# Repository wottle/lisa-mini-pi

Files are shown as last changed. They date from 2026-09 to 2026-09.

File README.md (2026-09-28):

# Lisa Mini Pi

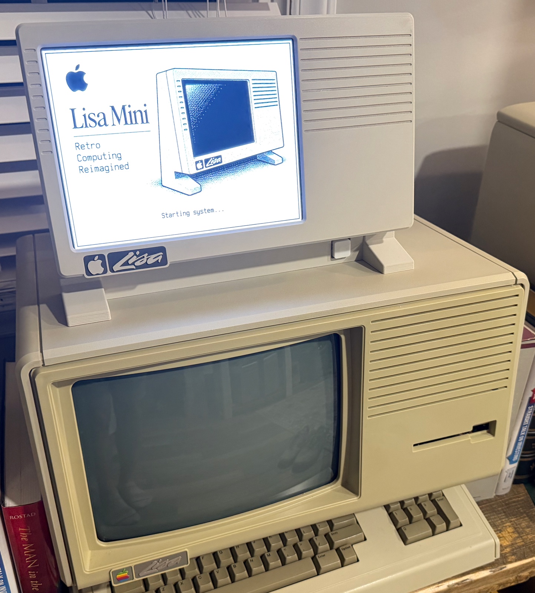
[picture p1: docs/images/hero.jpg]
Lisa Mini Pi booting, sitting atop a real Apple Lisa


A Raspberry Pi in a 3D-printed Apple Lisa-shaped case with a 1024x768 HDMI
LCD panel, booting straight into a "CHOOSE YOUR ADVENTURE" kiosk launcher
that lets you pick which vintage system to run:

- **Apple Lisa** — Office System 3.1, via a patched `LisaEm`
- **Classic Mac OS 6** — via Mini vMac
- **Classic Mac OS 7** — via Basilisk II
- **NeXTSTEP 3.3** — via Previous
- **Apple II** — via LinApple, boots straight into Total Replay (a
  ready-to-play library of Apple II games)

A physical GPIO power button + LED are wired up for the systems that
support a clean button-triggered shutdown (Lisa, NeXT, Apple II) — see
`docs/software-setup.md` §2.

## Screenshots

All on real hardware, 2026-09-27.

<table>
<tr>
<td align="center" width="33%">
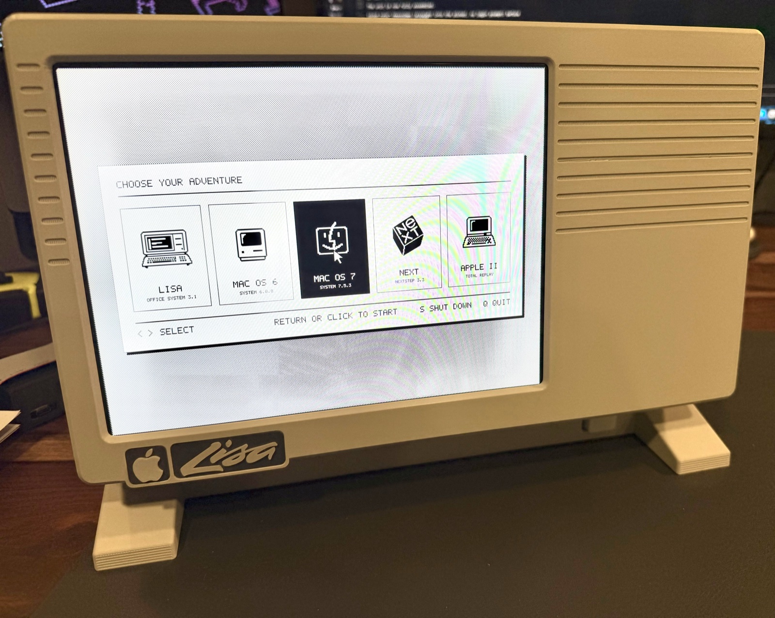
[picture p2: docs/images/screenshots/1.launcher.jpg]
<br>
<sub>The "CHOOSE YOUR ADVENTURE" picker</sub>
</td>
<td align="center" width="33%">
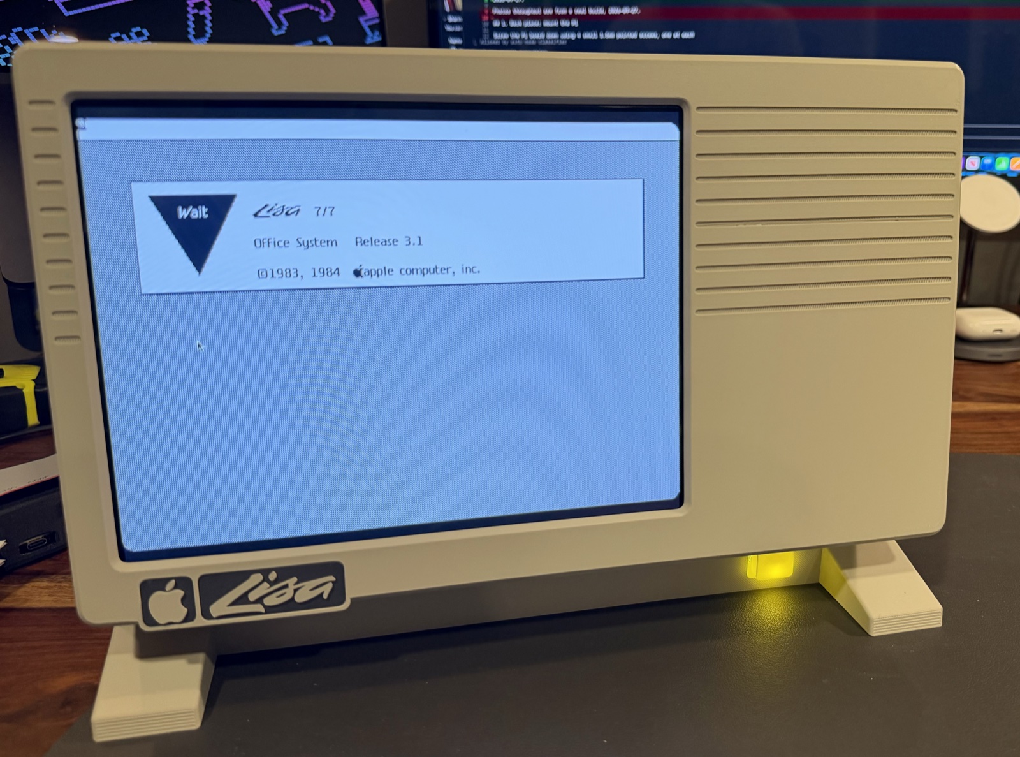
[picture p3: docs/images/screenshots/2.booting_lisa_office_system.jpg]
<br>
<sub>Lisa Office System 3.1 booting</sub>
</td>
<td align="center" width="33%">
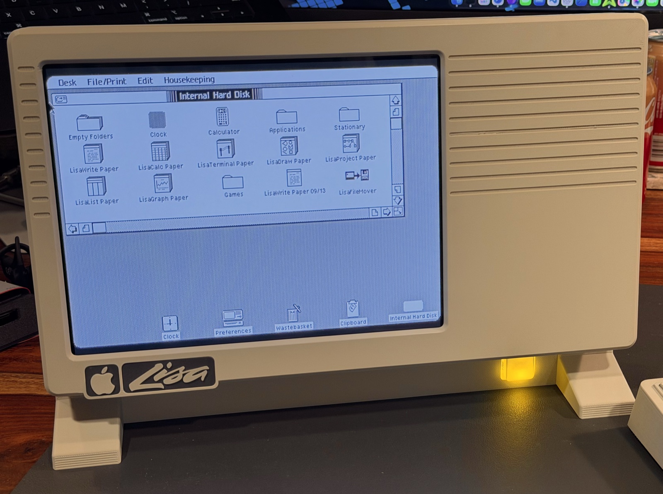
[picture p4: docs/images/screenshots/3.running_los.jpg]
<br>
<sub>Lisa Office System 3.1 running</sub>
</td>
</tr>
<tr>
<td align="center" width="33%">
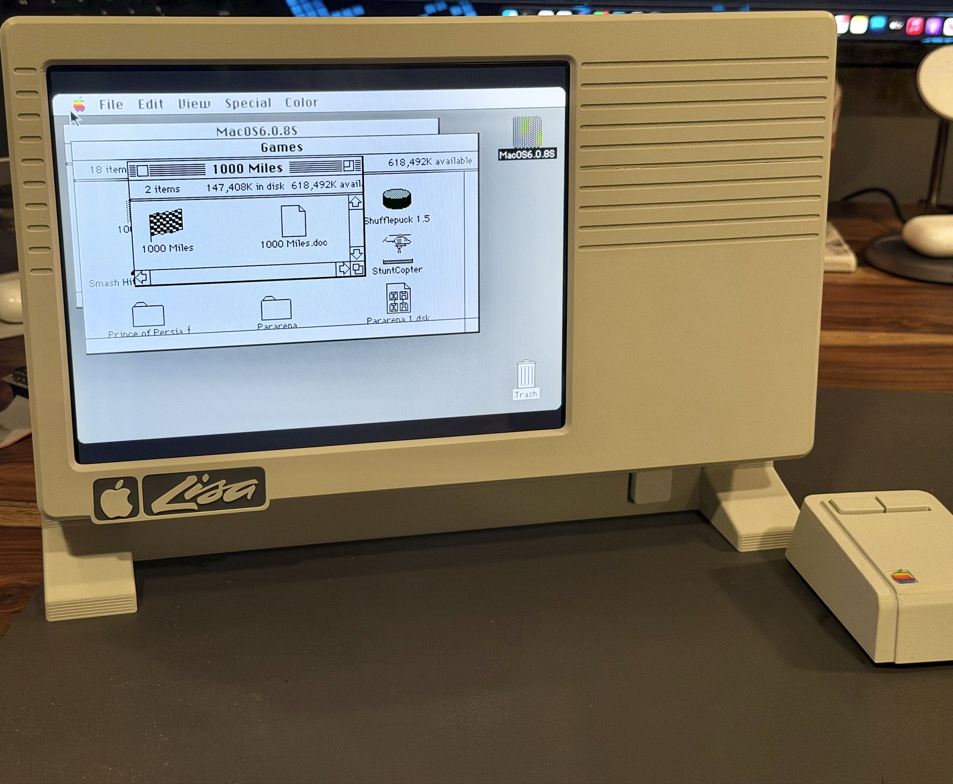
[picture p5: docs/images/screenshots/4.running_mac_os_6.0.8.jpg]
<br>
<sub>Classic Mac OS 6.0.8, via Mini vMac</sub>
</td>
<td align="center" width="33%">
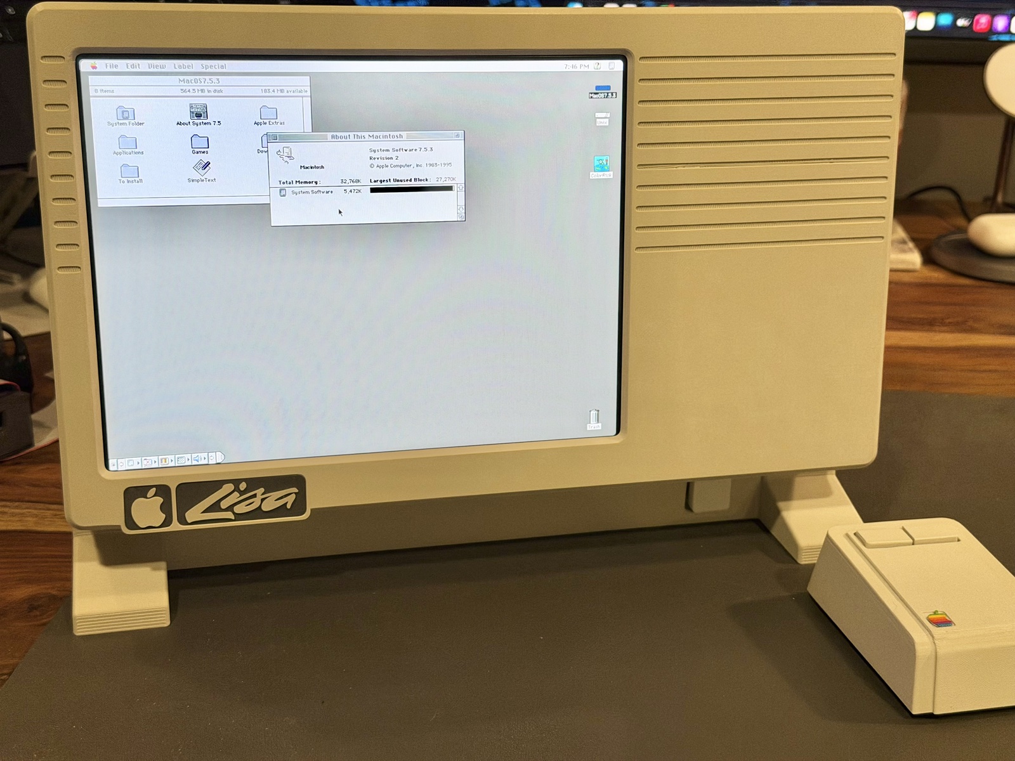
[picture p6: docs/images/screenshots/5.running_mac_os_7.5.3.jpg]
<br>
<sub>Classic Mac OS 7.5.3, via Basilisk II</sub>
</td>
<td align="center" width="33%">
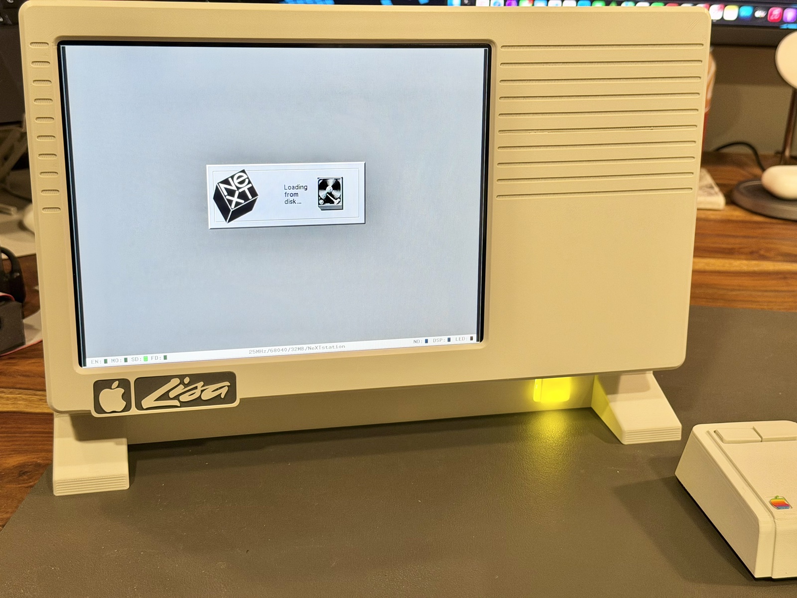
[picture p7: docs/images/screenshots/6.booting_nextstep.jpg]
<br>
<sub>NeXTSTEP 3.3 booting, via Previous</sub>
</td>
</tr>
<tr>
<td align="center" width="33%">
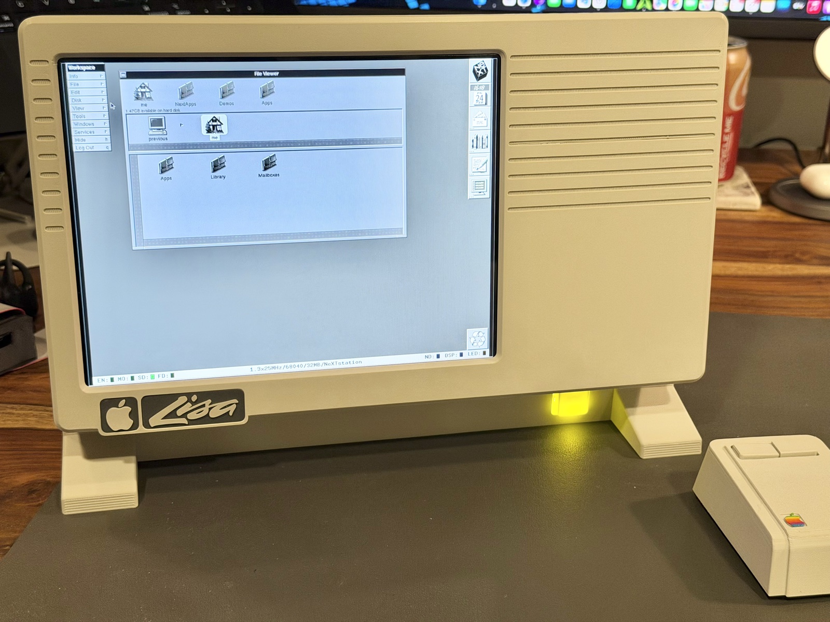
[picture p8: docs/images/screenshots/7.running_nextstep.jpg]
<br>
<sub>NeXTSTEP 3.3 running, via Previous</sub>
</td>
<td align="center" width="33%">
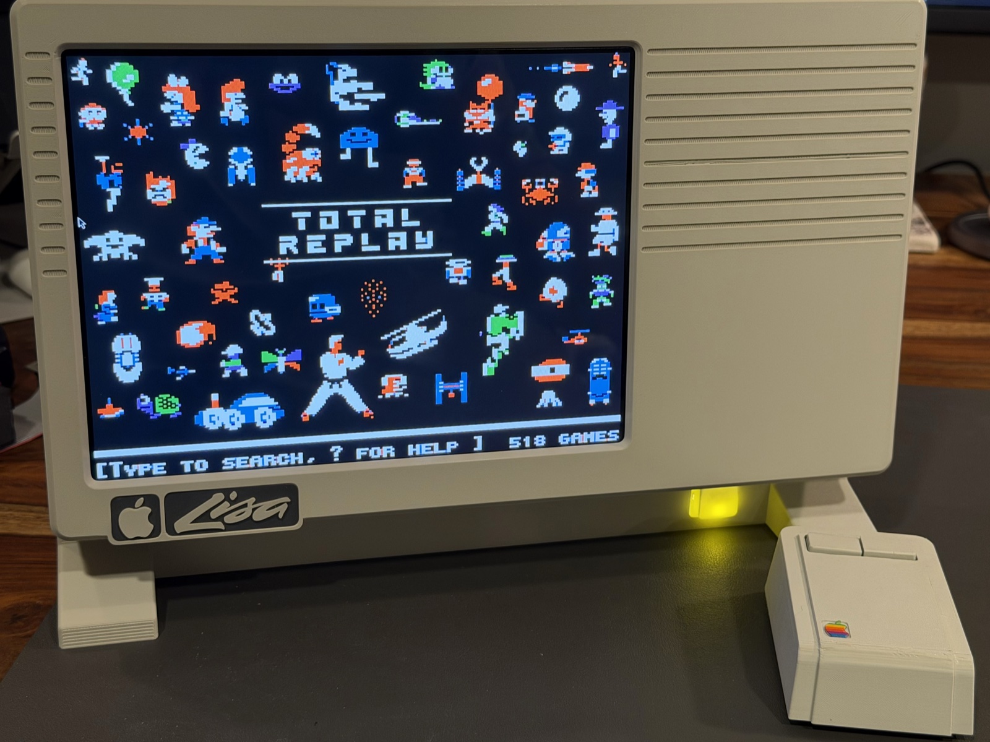
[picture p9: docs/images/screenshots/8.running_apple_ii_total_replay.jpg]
<br>
<sub>Apple II Total Replay, via LinApple</sub>
</td>
<td width="33%"></td>
</tr>
</table>

## Controls

At the picker: arrow keys or mouse hover to select, Return or click to
launch. Once inside an emulator, shut it down from the guest OS itself
(or the physical power button, where wired) to return to the picker.

- **SHUT DOWN** (`S`, or click its footer text) and **QUIT** (`Q`, or
  click its footer text, which switches to the full Raspberry Pi Desktop)
  both open a confirmation dialog first — too disruptive to fire on a
  single accidental key/click. Confirm with Return or by clicking
  CONFIRM; cancel with Escape or by clicking CANCEL.
- **Reboot** (`R`) is a hidden shortcut — not shown in the footer, and
  runs immediately with no confirmation.
- Escape/Ctrl+C don't get you out of the kiosk — none exist by design.

## Project status: work in progress

**Hardware support**: the full software stack (all five emulators, the
kiosk launcher, `provision.sh`) has been fully tested end-to-end on both
a Pi 3 and a Pi 5, in addition to the **Pi 4, which remains the
recommended target**. Where the other two currently fall short:

- **Pi 3**: works, but emulator performance is noticeably worse,
  especially Previous and LinApple - see
  `software/lisa-pi-launcher/CLAUDE.md` for specifics.
- **Pi 5**: the software side is fully working, but the current
  3D-printed case has no mounting for the dedicated power board a Pi 5
  needs to be powered reliably through the GPIO header (a plain
  12V→5V buck converter, fine for a Pi 4, isn't a reliable power source
  for a Pi 5) - full physical Pi 5 support is pending a case revision
  that adds that mounting.

The case, hardware choices, and software here all still reflect one
specific build (Pi 4, iPad 1/2 LCD panel, 1024x768) otherwise. Nothing
about that is locked in - expect breaking changes to the hardware and/or
software as these are explored:

- **An iPad 3/4 LCD panel + a Pi 5 dual-power board**, together (not
  separately) — specific parts already in hand as of 2026-09-27, not yet
  built. Higher resolution than the current iPad 1/2 panel, and since the
  new panel's driver board runs on 5V rather than 12V, this combination
  could also drop the current external 12V→5V buck converter entirely -
  a separate, nicer-to-have bonus on top of (not a substitute for) the
  Pi 5 power-board case mounting noted above, which a future case
  revision needs regardless of which LCD panel it ends up paired with.
  See `hardware/assembly/README.md`'s "Future revision being explored"
  section for the parts and reasoning.
- **An 11.6" widescreen LCD front panel**, which would need real
  software changes (the launcher's whole layout is currently hardcoded
  for a fixed 1024x768 4:3 panel - see `theme.py`'s docstring) to fit
  the Pi's actual display area into a widescreen opening correctly,
  not just a case redesign.

If you're building from this repo today, assume the specific
combination it documents (case STLs, BOM, `provision.sh`, the 1024x768
picker layout) rather than the abstract idea of "a Lisa Mini Pi" - any
of it may shift under a future build.

## Setting up a new Pi

**Do this before any hardware assembly** — get the Pi fully set up and
all five systems confirmed working on the bare board first (see
`hardware/bill-of-materials.md` for the ROM/disk assets), *then* build
the case around it (`hardware/assembly/README.md`). Debugging a wiring
or software issue is far easier with everything exposed on a desk than
after it's screwed and glued into a closed case.

```
git clone https://github.com/wottle/lisa-mini-pi.git ~/lisa-mini-pi
~/lisa-mini-pi/scripts/provision.sh
```

Automates everything installable without copyrighted assets - every
emulator build/install, the kiosk launcher, GPIO/LED wiring setup,
systemd units, and the boot splash. **There's no pre-packaged SD card
image**: every emulator needs a ROM and/or OS disk image that this
project has never redistributed (see "not redistributed here"
throughout `docs/software-setup.md`) - baking those into a public image
would be a real copyright problem. `provision.sh` prints exactly which
files to place where once it's done; read it before running it, like
any script that calls `sudo`.

## Layout

- `hardware/3d-models/` — case/enclosure STL files, print quantities, and
  the two back-piece variants (with/without a physical power button).
- `hardware/bill-of-materials.md` — everything else needed to build one:
  the Pi, LCD panel, power supply, switch, LED, wiring.
- `hardware/assembly/` — build/assembly instructions (placeholder, not yet populated).
- `scripts/provision.sh` — automates the software setup below on a fresh
  Pi; see "Setting up a new Pi" above.
- `software/lisa-pi-launcher/` — the kiosk launcher (Python), including the
  GPIO power-button/LED scripts and the systemd units that run it on boot.
- `docs/software-setup.md` — end-to-end setup guide: building the patched
  LisaEm, installing every emulator, wiring the physical power
  button/LED, the boot splash, and the boot-time systemd setup.
- `software/lisa-pi-launcher/SETUP.md` — a second, older setup doc
  covering the launcher/LisaEm/Basilisk II/Mini vMac in more detail; it
  does not cover Previous or LinApple (see the note at its top).

## Related repos

- [`wottle/lisaem`](https://github.com/wottle/lisaem) (branch
  `lisa-fixes-1024x768`) — patched fork of `arcanebyte/lisaem` used for the
  Apple Lisa environment. See `docs/software-setup.md` for what's patched
  and why.

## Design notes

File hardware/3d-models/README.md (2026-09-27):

# 3D Models

STL files for the Lisa Mini Pi case, sized around the repurposed iPad
1/2 LCD panel + controller board (see `../bill-of-materials.md`).

| File | Qty | Notes |
|---|---|---|
| `Lisa-Mini-Pi_Front-iPad-LCD.stl` | 1 | Front panel/bezel, cut for the iPad 1/2 LCD. |
| `Lisa-Mini-Pi_Back-With_Power_Button.stl` | 1 | Back piece **with** a cutout for the keyboard-switch power button + LED. Use this one, not the no-button variant, if you're wiring up the GPIO power button (see `../../docs/software-setup.md` §2). |
| `Lisa-Mini-Pi_Back-NO_Power_Button.stl` | 1 | Back piece with **no** power-button cutout - print this instead if you don't want the extra wiring/parts of a physical power switch. Print exactly one back piece, not both. |
| `Lisa-Mini-Pi_Power-Button.stl` | 1 | The power button cap/bezel itself - only needed with the "With Power Button" back piece. |
| `Lisa-Mini-Pi_LCD-Bottom-Clips_qty2.stl` | **2** | Bottom clips holding the LCD panel in place - print **two** of this part (the `qty2` in the filename is the actual required count, not a typo/leftover). |
| `Lisa-Mini-Pi_LCD-Side-Clips_qty2.stl` | **2** | Side clips holding the LCD panel in place - print **two** of this part as well. |
| `Lisa-Mini-Pi_Lisa-Badge.stl` | 1 | Decorative Lisa logo badge. |
| `Lisa-Mini-Pi_Blank-Small-Badge.stl` | 1 | Blank badge variant, if you'd rather not print the Lisa logo. |
| `Lisa-Mini-Pi_All-Plates.3mf` | - | Slicer project file with every part above laid out on build plates together - open this instead of the individual STLs if your slicer supports `.3mf` and you want everything queued up at once. |

Raspberry Pi mounting fits a Pi 3B, 4B, or 5 - **Pi 4B is the
recommended target**: better performance than a Pi 3B (see
`../bill-of-materials.md`), and unlike a Pi 5, its power needs are
already covered by this case's buck-converter wiring. A Pi 5 boots and
runs the full software stack fine, but this case has no mounting yet for
the dedicated power board a Pi 5 needs for reliable GPIO power delivery -
see the main README's "Project status" for detail.

Assembly instructions (fitting the LCD, wiring the power button, closing
the case) live in `../assembly/README.md`.

## Printing notes

General starting-point settings, carried over from the same builder's
[LisaFPGA case](https://github.com/wottle/lisa-mini/blob/main/docs/PRINTING.md)
(a different, larger case design, but the material and general settings
transfer):

| Setting | Value |
|---|---|
| Wall thickness | ~2.4mm (2 perimeters at 0.4mm nozzle, or adjust to match) |
| Infill | 15–20% |
| Layer height | 0.2mm for most parts; 0.12mm with ironing enabled for `Lisa-Mini-Pi_Lisa-Badge.stl`/`Lisa-Mini-Pi_Blank-Small-Badge.stl` (surface quality on a flat visible logo plate) |
| Material | [Polar Filament Retro Platinum PLA](https://polarfilament.com/products/retro-platinum-pla-1kg-1-75mm) — metallic silver/platinum finish for a classic-computing look; no warping issues on the LisaFPGA case's large front/back shells with this filament |

**Not yet verified for this specific case's parts** (unlike the settings
above, which are safe general-purpose starting points): per-part print
orientation, which parts need supports, and the actual bed size required
- `Lisa-Mini-Pi_All-Plates.3mf` already lays every part out on build
plates, so opening that in your slicer is the fastest way to get real
orientation/plating without guessing. If you print from scratch and
learn anything worth recording here (a part that needs supports, an
orientation that avoided them, the bed size the `.3mf` plates assume),
please contribute it back.

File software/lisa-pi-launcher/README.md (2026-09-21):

# Lisa Boot Launcher

A fullscreen Raspberry Pi kiosk app styled after the Apple Lisa's hardware
self-test/startup screen. Appears immediately after boot and lets you pick
which vintage computer environment to start (currently LisaEm; Basilisk II
planned).

See `docs/superpowers/specs/2026-09-16-lisa-boot-launcher-design.md` for
the full design rationale.

## Running it standalone (development)

```
python3 -m venv venv
source venv/bin/activate
pip install -r requirements.txt
python3 gen_icons.py   # only needed once, or after changing an icon
python3 launcher.py
```

Press Escape... actually there is no Escape/quit binding by design (it's a
kiosk); use Ctrl+C in the terminal you launched it from during development,
or `S`/`R`/`Q` to shut down/reboot/switch to the full desktop on real
hardware. `Q` only works when `system/back-to-kiosk.desktop` and the
`lightdm`/watchdog setup from `SETUP.md` are installed - without them it's
equivalent to Ctrl+C (the kiosk just respawns via `Restart=always`).

## Configuration

Edit `config.json` to add/remove systems. Each entry needs `id`, `name`,
`subtitle`, `icon` (path to a PNG), and `command` (an argv list, not a
shell string) that blocks until the emulator exits.

## Controls

- Left/Right arrow: change selection
- Enter: launch the selected system
- S: shut down the Pi
- R: reboot the Pi
- Q: switch to the full Raspberry Pi Desktop (see the caveat above); an
  "Emulator Launcher" desktop icon returns to the kiosk

## Running the tests

```
python3 -m pytest
```

## Installing as the boot-time kiosk

See `system/launcher.service` and the "Display/session integration"
section of the design spec for the minimal-X11-session autostart setup.

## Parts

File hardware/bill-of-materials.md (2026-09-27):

# Bill of Materials

Everything needed to build one Lisa Mini Pi, beyond the 3D-printed parts
in `3d-models/` (see that directory's README for exact STL files/print
quantities).

**Links are convenience references, not endorsements or guaranteed
current** - Amazon/AliExpress listings change/disappear; verify specs
against the notes here before ordering if a link is dead or looks
different than described.

Full wiring diagram (buck converter power, switch, LED, exact pins):
`pi-wiring-diagram.svg`.

| Part | Qty | Notes | Link |
|---|---|---|---|
| Raspberry Pi | 1 | **Pi 4B recommended.** A Pi 3B works but struggles with Previous/LinApple in particular (see `../software/lisa-pi-launcher/CLAUDE.md`); a Pi 5 runs everything fine but this case's power wiring (below) doesn't yet reliably support one - see the main README's "Project status". Case mounts fit all three. | — |
| microSD card, 32GB | 1 | Real measured usage on a fully-loaded Pi 4 (all five emulators, all disk images): 13GB used of a 29GB card (2026-09-26) - 32GB gives comfortable headroom; go 64GB if you want more margin for future growth (e.g. larger assets if the project moves to a higher-res LCD panel) or just don't want to think about it again. 16GB would be uncomfortably tight. | — |
| iPad 1/2 LCD panel + controller board | 1 | "Type 2 with LCD" listing appears to be the correct fit. | [AliExpress](https://www.aliexpress.us/item/3256801532761537.html) |
| 12V→5V buck converter | 1 | Powers the Pi from the same 12V supply as the LCD. **Adjustable output** - ships set to an arbitrary voltage; must be calibrated to ~5.1V with a multimeter before ever connecting it to the Pi's GPIO pins, every time, even on a converter you've calibrated before. See `assembly/README.md` §5. | [Amazon](https://a.co/d/07PxophW) |
| 12V 5A power supply | 1 | Powers the buck converter (→ Pi) and the LCD controller board. | — (any reputable 12V/5A barrel-jack supply) |
| 5.5x2.5mm barrel jack (panel-mount, female) | 1 | The case's main power *input* - mounts through the hole in the back piece (secured with its own washer/nut), feeding the rocker switch. See `assembly/README.md` §2. | [Amazon](https://a.co/d/0buA0dI0) |
| 5.5x2.5mm barrel jack (pigtail, male) | 1 | A second one, wired to a short pigtail, to connect the rocker switch's output to the LCD controller board's own 12V barrel-jack input (if your controller board takes power that way - see `assembly/README.md` §3). Confirmed correct listing (2026-09-27) - a different part than the panel-mount jack above. | [Amazon](https://a.co/d/0fmf5a9l) |
| Rocker switch | 1 | Master power switch for the LCD + Pi (cuts 12V before the buck converter/LCD controller, upstream of the GPIO soft-power button below) - see `assembly/README.md` §2. | [Amazon](https://a.co/d/02DKKr63) |
| Keyboard switch (clear housing recommended, for the light-up GPIO power button) | 1 | Only needed if printing the "With Power Button" back piece - see `3d-models/README.md`. Confirmed correct listing (2026-09-27) - was out of stock as of this writing, so it may need a substitute if still unavailable. | [Amazon](https://a.co/d/05LYYxer) |
| 3mm warm white or yellow LED | 1 | Lights the GPIO power button - see `../docs/software-setup.md` §2 for the GPIO18 wiring. | [Amazon](https://a.co/d/0dTjaJSu) |
| Dupont wires (assorted M/F) | several | For GPIO connections (LED, power-button switch) - see `../docs/software-setup.md` §2 for exact pins. | [Amazon](https://a.co/d/07OlQIg0) |
| 20 AWG wire | a few feet | Power distribution: 12V jack → toggle switch → buck converter, and 12V jack → toggle switch → LCD controller board. | — |
| Resistor, 330Ω | 2 | One inline with the power-button switch (3.3V → resistor → switch → GPIO17), one inline with the LED (GPIO18 → resistor → LED → GND) - both confirmed on real hardware (2026-09-27). See `../docs/software-setup.md` §2. | — |
| Heat-shrink tubing, assorted | a few feet | Insulates every soldered connection in the power/switch/LED wiring before it's routed into the case - see `assembly/README.md` §4. | — |
| M3×4mm screws | 8 | Mounts the LCD's side clip (1), bottom clips (2), and the controller board(s) (2 each - 4 if there's an optional button board too) - see `assembly/README.md` §6-7. | — |
| 1.5mm pointed screws (small) | 4 | Mounts the Pi board to the back piece. **Go easy on these** - the printed screw mounts are delicate and have cracked on at least one build; hot glue is a working fallback if a mount breaks. See `assembly/README.md` §1. | — |
| Kapton tape | small roll | Optional - useful for pinning down an auxiliary/button board's wiring if it has no mounting holes of its own. | — |
| Multimeter | 1 | Required to calibrate the buck converter's output voltage before connecting it to the Pi - see the buck converter row above and `assembly/README.md` §5. Not consumed by the build; any basic multimeter works. | — |

## Open items

- Quantities above assume one Lisa Mini Pi; scale accordingly for more.

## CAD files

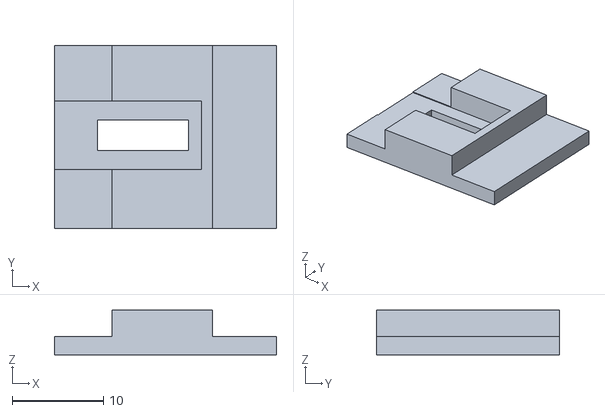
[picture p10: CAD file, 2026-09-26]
hardware/3d-models/Lisa-Mini-Pi_LCD-Side-Clips_qty2.stl
24.3 x 20.0 x 4.90

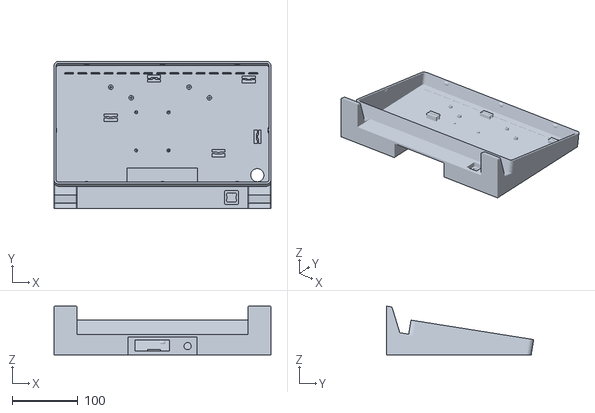
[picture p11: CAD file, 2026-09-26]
hardware/3d-models/Lisa-Mini-Pi_Back-With_Power_Button.stl
330.0 x 224.1 x 74.3

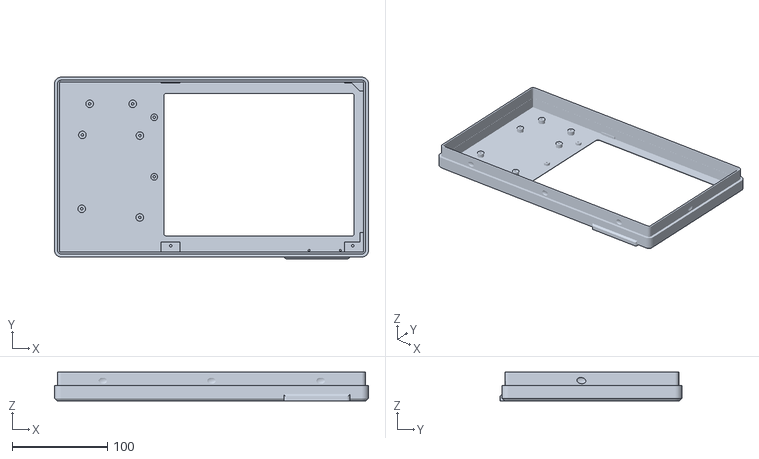
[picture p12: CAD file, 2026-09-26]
hardware/3d-models/Lisa-Mini-Pi_Front-iPad-LCD.stl
330.0 x 191.0 x 30.0

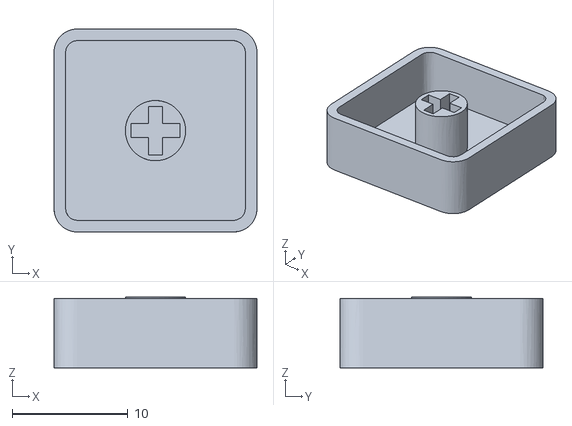
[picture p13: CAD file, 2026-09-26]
hardware/3d-models/Lisa-Mini-Pi_Power-Button.stl
17.5 x 17.5 x 6.10

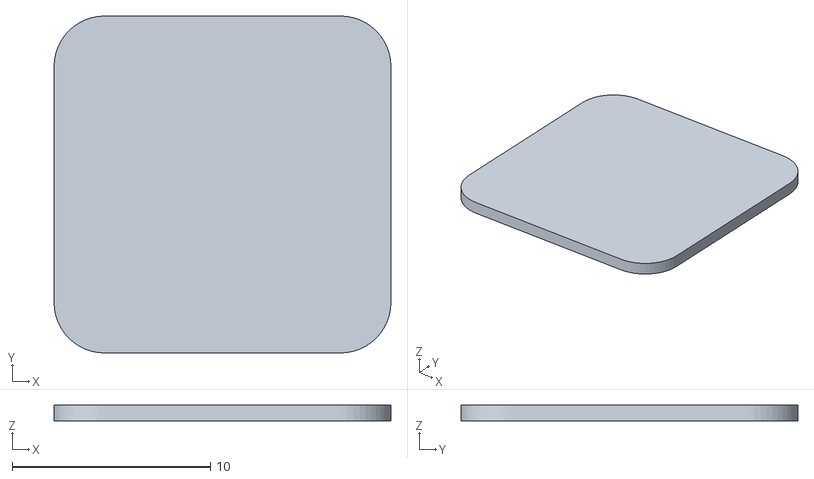
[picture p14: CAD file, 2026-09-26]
hardware/3d-models/Lisa-Mini-Pi_Blank-Small-Badge.stl
17.0 x 17.0 x 0.796

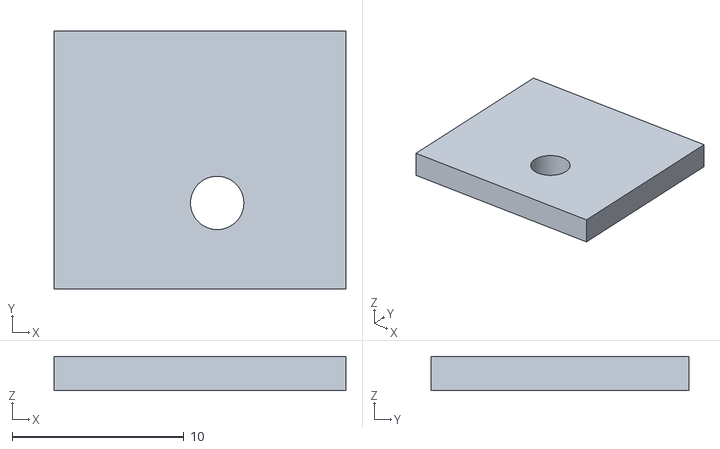
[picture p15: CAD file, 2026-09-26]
hardware/3d-models/Lisa-Mini-Pi_LCD-Bottom-Clips_qty2.stl
17.0 x 15.0 x 2.00

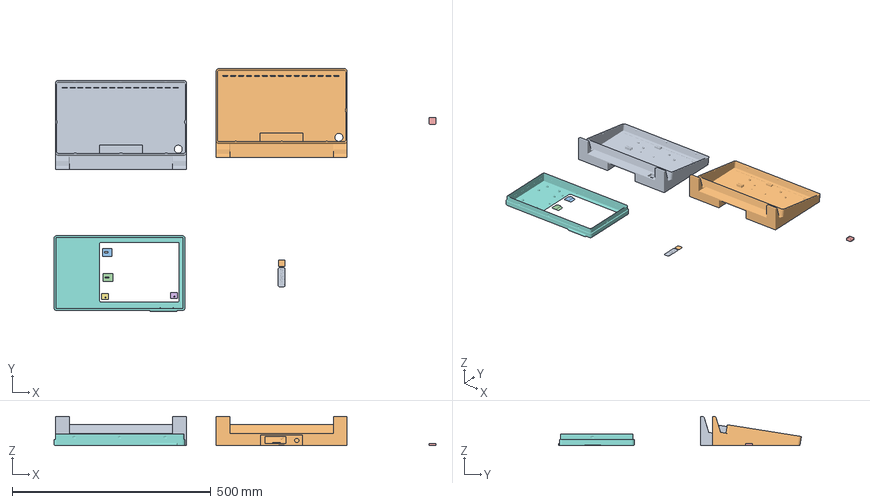
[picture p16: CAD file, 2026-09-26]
hardware/3d-models/Lisa-Mini-Pi_All-Plates.3mf
961.7 x 611.5 x 74.3 mm
Lisa-Mini-Pi_Back.obj
Lisa-Mini-Pi_Back-no-power-button.obj
Lisa-Mini-Pi_LCD-Side-Clips_qty2.obj x 2
Lisa-Mini-Pi_Power-Button.obj
Lisa-Mini-Pi_LCD-Bottom-Clips_qty2.obj x 2
Lisa-Mini-Pi_Front-iPad-LCD.obj
tinker.obj x 2

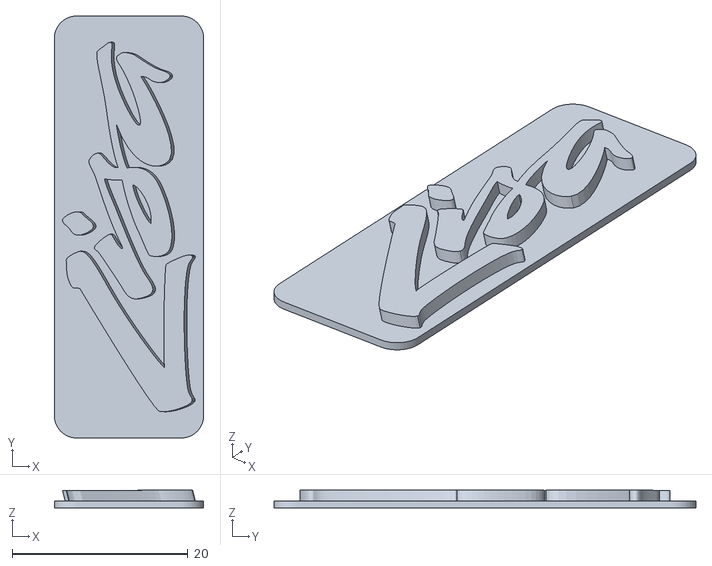
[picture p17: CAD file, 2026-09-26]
hardware/3d-models/Lisa-Mini-Pi_Lisa-Badge.stl
17.0 x 48.0 x 2.00

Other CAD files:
hardware/3d-models/Lisa-Mini-Pi_Back-NO_Power_Button.stl

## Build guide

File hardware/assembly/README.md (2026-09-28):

# Assembly Instructions

**Do the software setup first** (see the main README's "Setting up a new
Pi") — flash the Pi, run `provision.sh`, place your ROM/disk assets, and
confirm all five systems boot on the bare board before starting here.
Debugging a wiring or software issue is far easier with everything
exposed on a desk than after it's screwed and glued into a closed case.

Step-by-step build for the iPad 1/2 LCD + external buck-converter power
variant documented elsewhere in this repo (see `../3d-models/README.md`
for STL files/quantities, `../bill-of-materials.md` for parts, and
`../pi-wiring-diagram.svg` for the exact GPIO/power pinout referenced
throughout). Confirmed on a real build, with photos throughout,
2026-09-27.

## 1. Back piece: mount the Pi

Screw the Pi board down using 4 small 1.5mm pointed screws, one at each
corner mounting hole.

**Be careful when driving these screws — the printed screw mounts are
small and delicate.** All four cracked on one build despite not cracking
on earlier prints of the same model; the Pi was secured with hot glue as
a fallback in that case. Consider reinforcing/thickening these mounts in
the model, or just go slow and stop at the first sign of resistance
rather than forcing it.

## 2. Back piece: power jack and rocker switch

1. Insert the DC barrel jack through its hole in the back of the case,
   and secure it from inside with the washer and nut it comes with.
2. Pop the rocker switch into the larger hole in the back piece (press
   fit).
3. Wire the rocker switch so it's the master cutoff for both the LCD and
   the Pi (via the buck converter):
   - Solder the barrel jack's **positive (red)** wire to one blade on
     the back of the rocker switch.
   - The barrel jack's **negative (black)** wire splits to two black
     wires — one eventually goes to the buck converter's input, the
     other to the LCD controller board's power input.
   - Both **red** power wires (the ones heading to the buck converter
     and the LCD controller) get soldered together to the rocker
     switch's **other** blade.
   - Net result: flipping the rocker switch cuts power to the LCD and to
     the Pi (through the buck converter) at the same time.

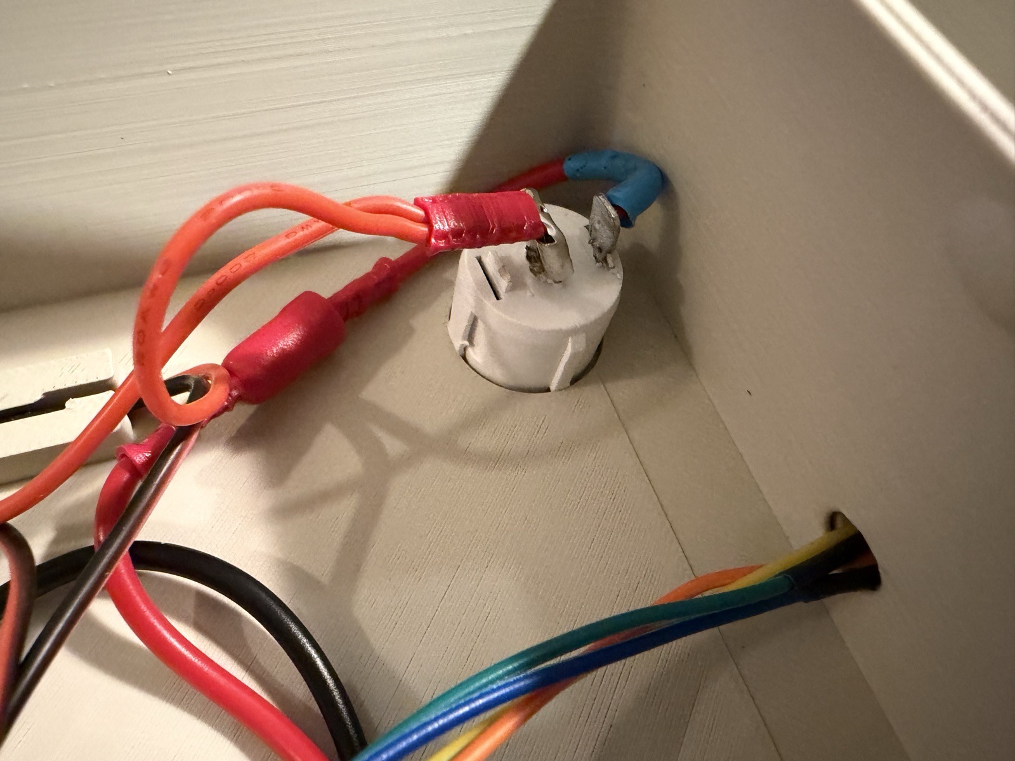
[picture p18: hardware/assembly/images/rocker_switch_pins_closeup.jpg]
Rocker switch terminals, wires soldered on and heat-shrunk


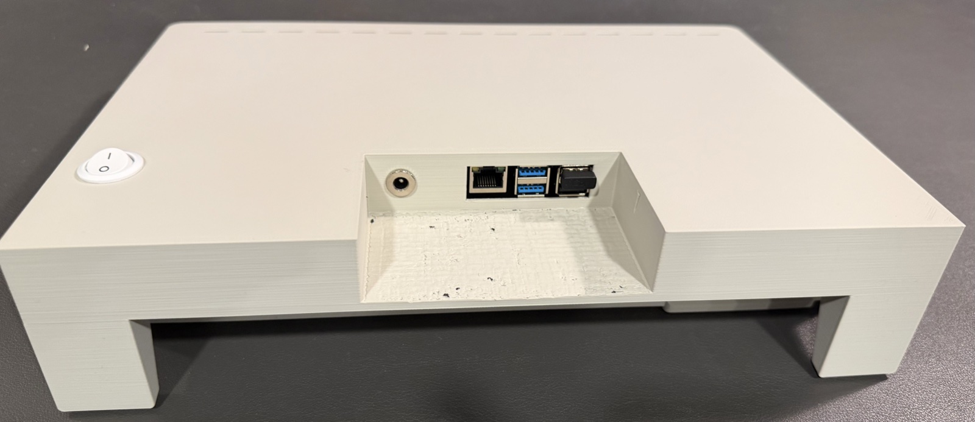
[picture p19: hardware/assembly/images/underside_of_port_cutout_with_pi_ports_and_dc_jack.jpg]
Barrel jack and rocker switch installed, seen from outside the back piece


## 3. Back piece: buck converter and LCD controller power

1. Screw the buck converter down onto one of the two sets of standoffs
   on the inside of the back piece.
2. Solder one of the black/red wire pairs from step 2 to the buck
   converter's input (negative/positive respectively).
3. For the LCD controller board's power input: if yours takes 12V via a
   barrel jack (as this build's does), terminate the other black/red
   wire pair in a barrel-jack plug and connect that to the controller
   board.

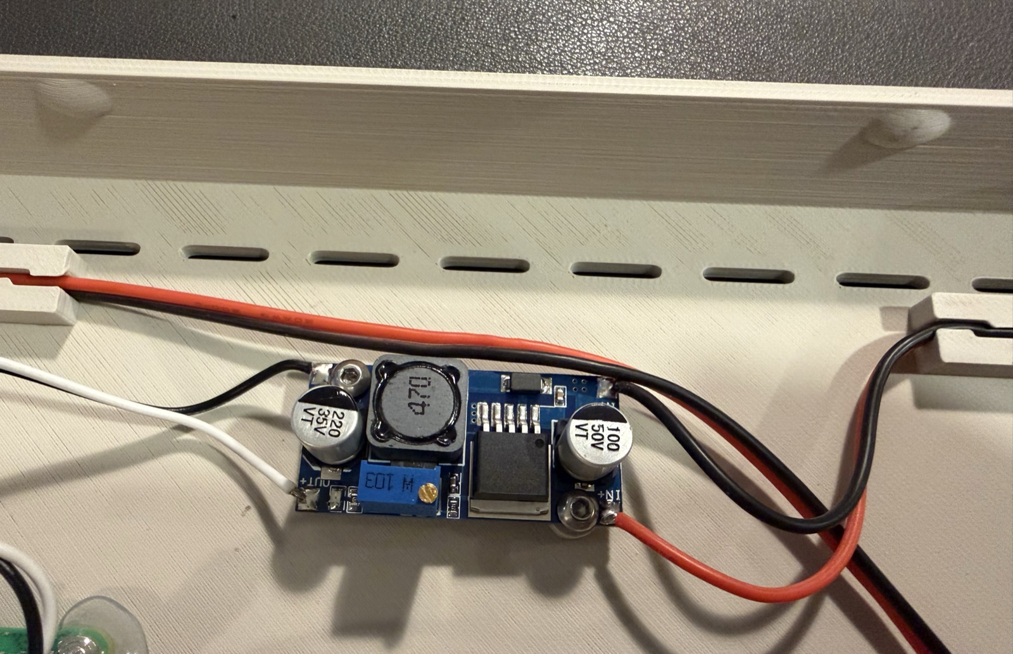
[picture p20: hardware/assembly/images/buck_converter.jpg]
Buck converter mounted on its standoffs, input/output wires soldered on


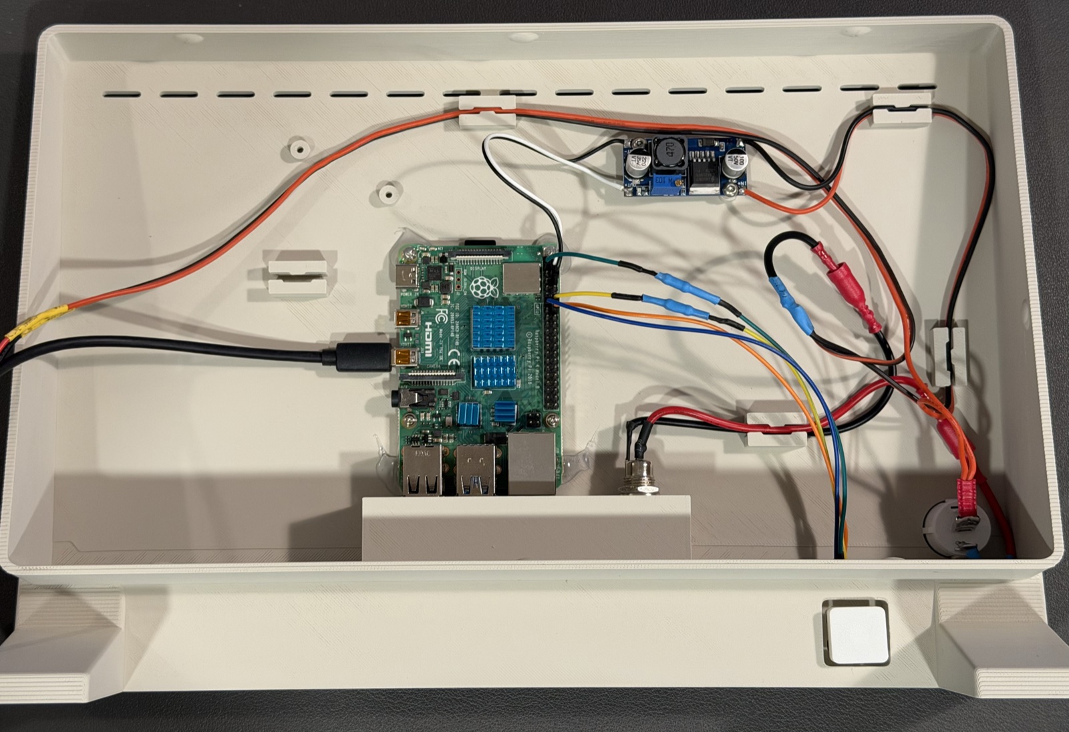
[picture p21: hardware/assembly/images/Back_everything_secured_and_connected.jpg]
Back piece with Pi, buck converter, and switch/LED wiring all in place


## 4. Back piece: power-button switch and LED

Wire the keyboard-switch power button and its LED per
`../pi-wiring-diagram.svg`:

1. Solder a Dupont wire to each of the two legs on the back of the
   keyboard switch, and a Dupont wire to each of the LED's two legs (4
   wires total).
2. Add an inline 330Ω resistor on **one** of the switch's two wires, and
   on the LED's **positive** leg wire — matching R1/R2 in the wiring
   diagram.
3. Heat-shrink every connection so nothing can short once it's routed
   into the case.
4. Mount the LED: most keyboard switches have a slot the LED's legs can
   run through. Route them through it, then secure the LED close to the
   switch's base with a dab of hot glue — this keeps it from touching or
   rubbing the switch's keycap when pressed. LED orientation (legs toward
   the top or bottom of the switch) doesn't matter functionally; this
   build used bottom.
5. Feed all 4 wires off the bottom of the switch through the hole in the
   front of the back piece (the one that opens into the case interior).
   It's easier one wire at a time — start with the two that have inline
   resistors, since they're the least flexible to maneuver.
6. Push the keyboard switch's keycap down into its slot — it should
   click lightly into place.
7. Plug the 4 Dupont wires into the GPIO pins shown in the wiring
   diagram (GPIO17/3.3V for the switch, GPIO18/GND for the LED).

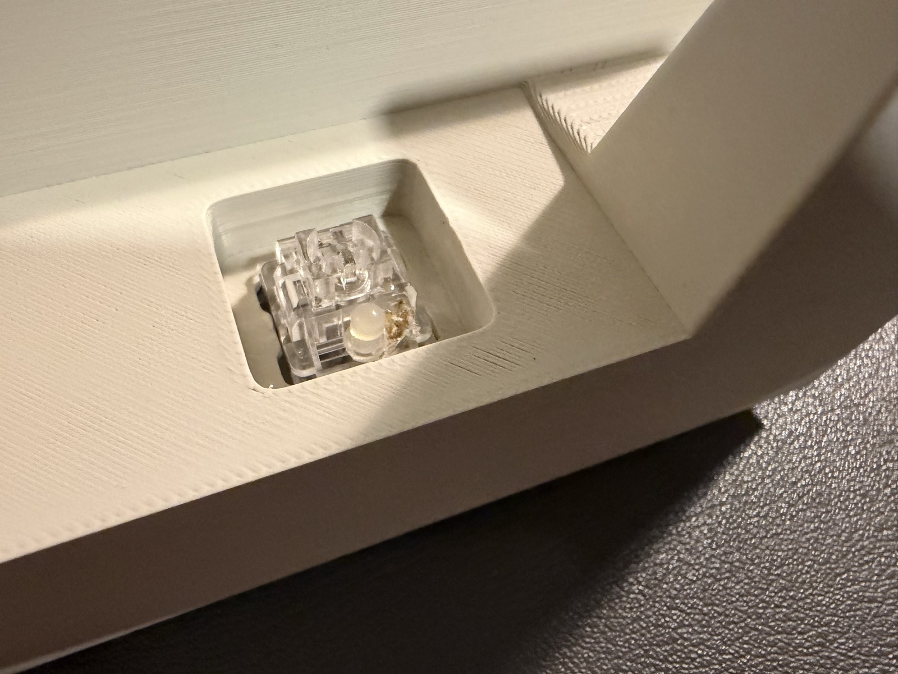
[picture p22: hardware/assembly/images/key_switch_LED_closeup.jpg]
Switch keycap seated in its slot, LED visible beside it


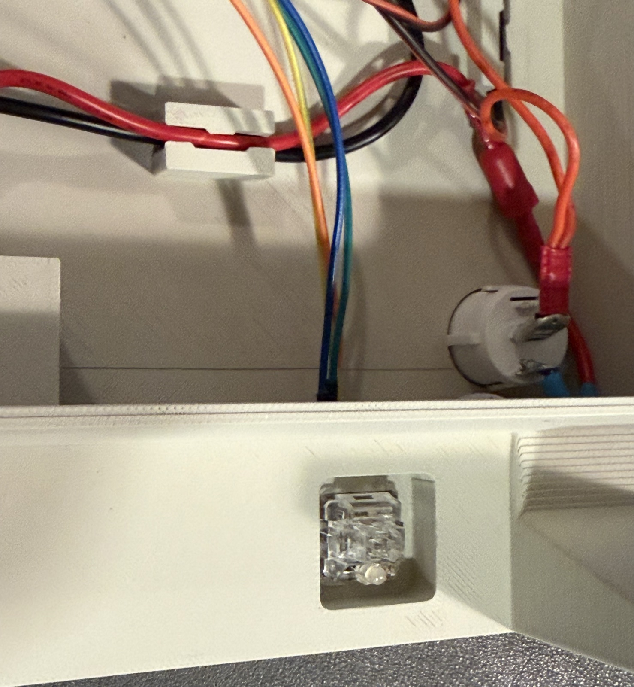
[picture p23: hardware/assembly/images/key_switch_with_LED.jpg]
Switch/LED wires routed through the case wall into the interior


## 5. Back piece: Pi power and video

1. **Before connecting anything to the Pi**, calibrate the buck
   converter's output: with the barrel jack's power connected and the
   rocker switch on, put a multimeter on the buck converter's output
   terminals and adjust its trim screw until it reads roughly **5.1V**.
   These converters ship set to an arbitrary voltage, not necessarily
   safe for the Pi - do this check every time, even if you've calibrated
   one before, and definitely before the next step ever touches the Pi's
   GPIO pins.
2. Run two more Dupont wires from the buck converter's output to the
   Pi's GPIO **Pin 2** (5V) and **Pin 6** (GND) — see the wiring diagram.
   This is how the Pi gets power in this build, not through its
   USB-C/micro-USB port — **never connect USB power at the same time**.
3. Plug a micro-HDMI-to-HDMI cable into the Pi.

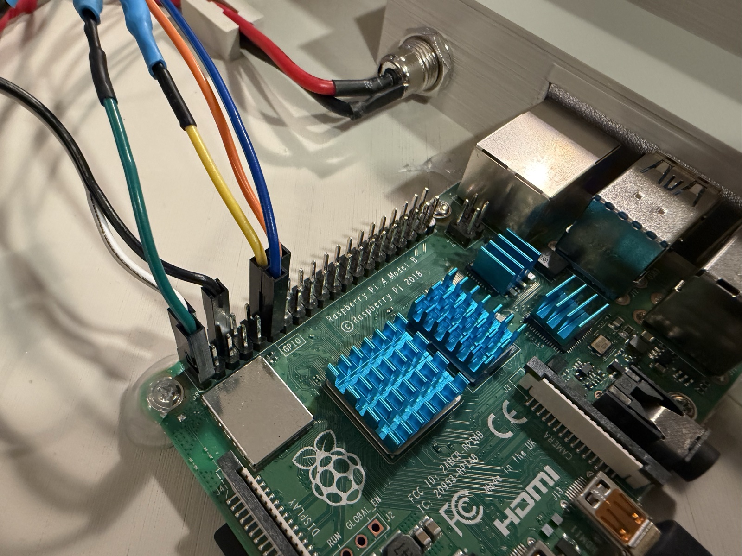
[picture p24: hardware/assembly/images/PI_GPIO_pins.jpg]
Switch/LED and buck-converter-power wires plugged into the Pi's GPIO header


The back piece is now complete.

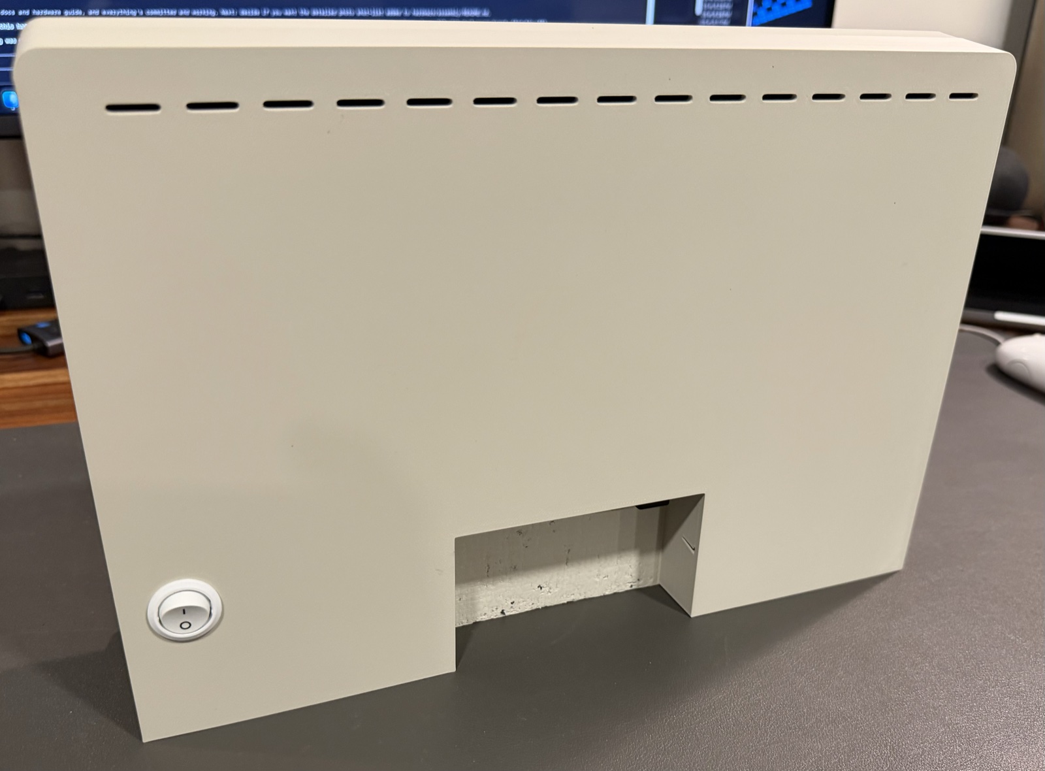
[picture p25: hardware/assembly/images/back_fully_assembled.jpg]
Back piece fully assembled, seen from outside


## 6. Front piece: mount the LCD panel

1. Check the LCD panel's edges first: many iPad LCD panels have small
   metal screw-down tabs sticking out on three sides (visible in the
   corner shot below). These may not sit flush enough for the panel to
   fit the case as printed - if not, bend the tabs flat against the
   panel's edge, or trim them off with wire snips (watch for sharp edges
   if you cut). Better to find this out now than after step 3's clip is
   already screwed down.
2. One corner of the front piece's 3D print has a notch sized for the
   LCD panel's corner. Start there: slide that corner in and push the
   panel all the way toward the case's thin edge.

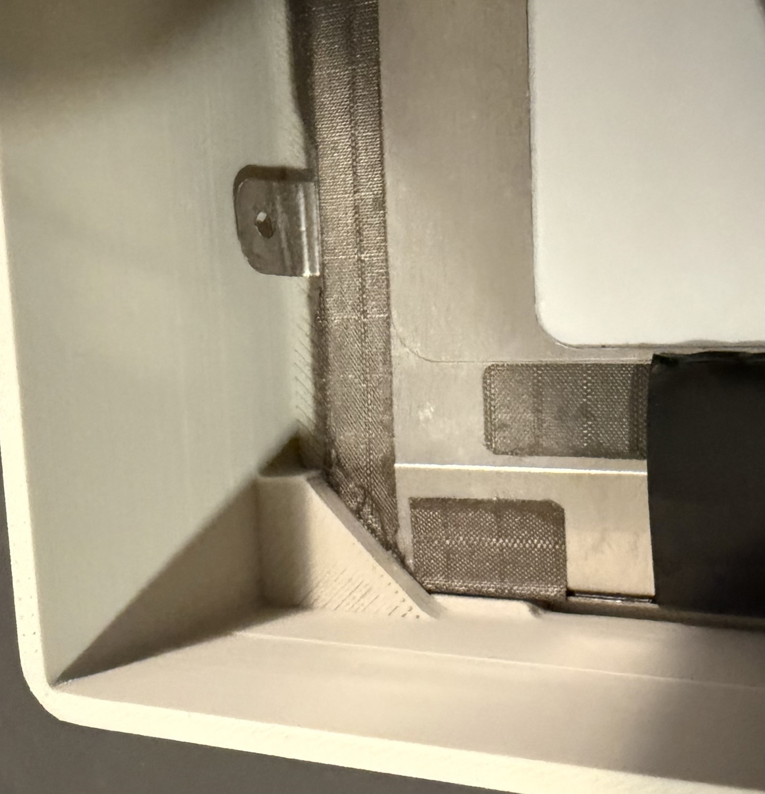
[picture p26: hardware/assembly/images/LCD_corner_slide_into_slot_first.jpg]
LCD panel's corner sliding into the front piece's notch - note the metal screw-down tab visible on this edge
   

3. Take a 3D-printed **side clip**, slide it over its standoff screw
   hole and over the LCD panel's edge, push it snug, then secure it with
   an M3×4mm screw.

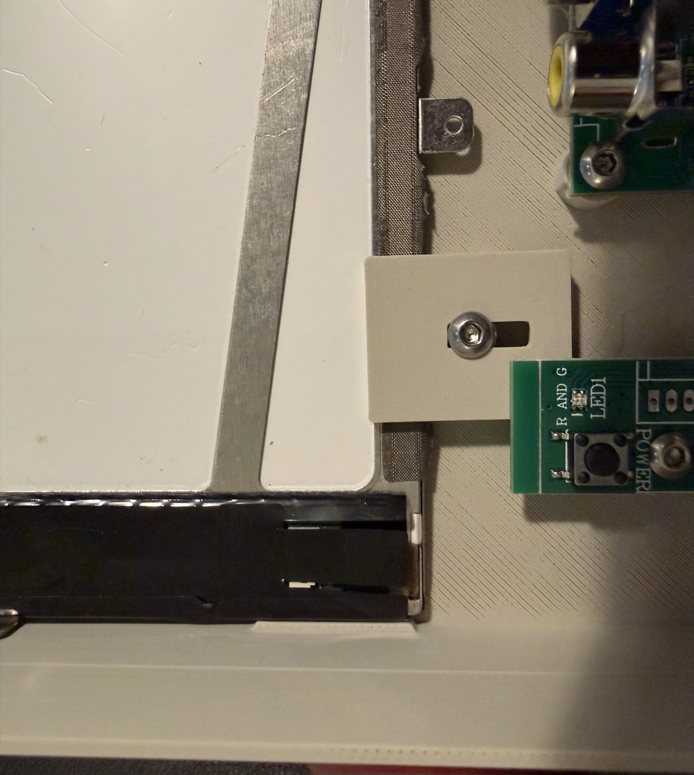
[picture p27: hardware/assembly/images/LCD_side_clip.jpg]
Side clip screwed down over the LCD panel's edge
   

4. Take the two 3D-printed **bottom clips** and screw each into its
   mounting block on the bottom of the case with an M3×4mm screw. The
   LCD panel should now be fully secured to the front piece.

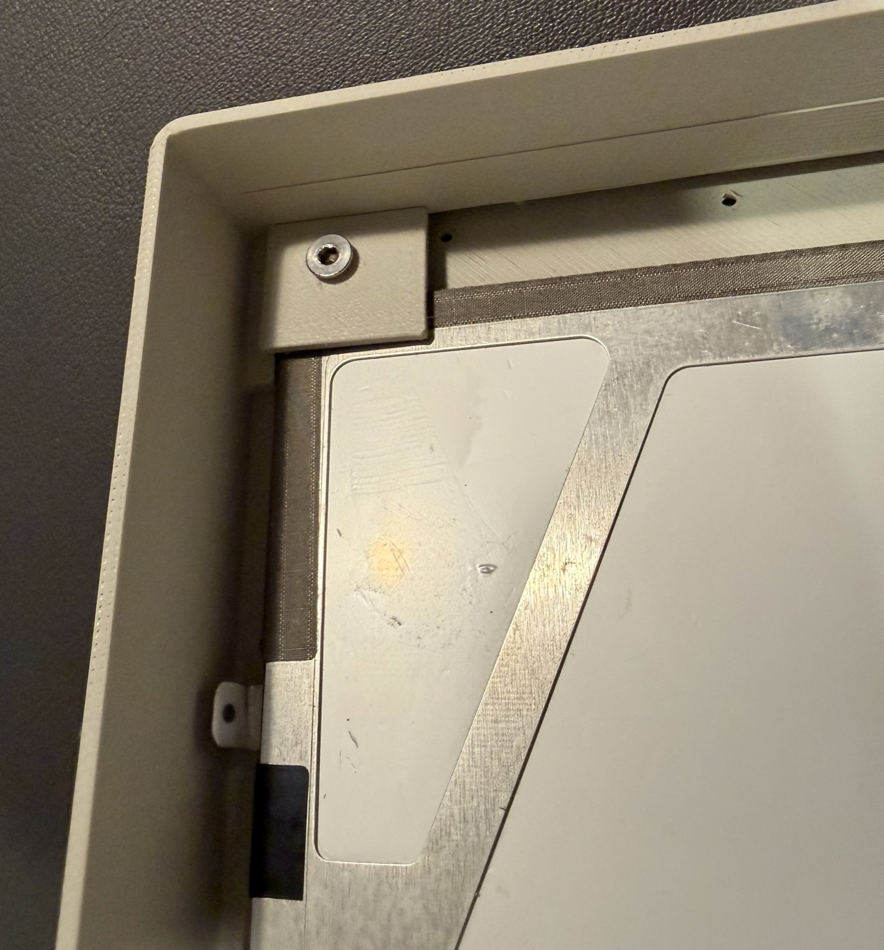
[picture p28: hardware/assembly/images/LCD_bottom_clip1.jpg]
Bottom clip #1 screwed into place
   
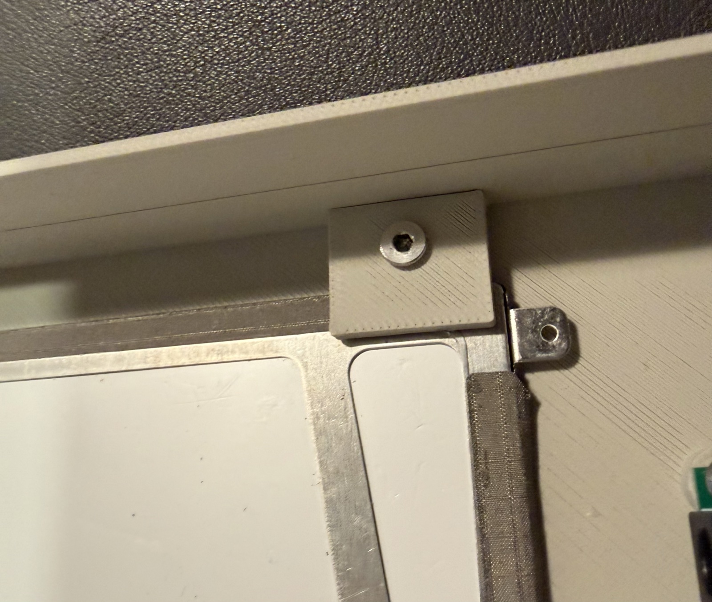
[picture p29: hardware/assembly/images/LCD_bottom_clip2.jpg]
Bottom clip #2 screwed into place
   

## 7. Front piece: mount the controller board(s)

1. Secure the LCD controller board (and the optional button board, if
   your panel kit has one) to the inside of the front piece, 2×
   M3×4mm screws each.
2. Tuck all wiring as flush against the front piece as you can — it has
   to close against the back piece later. Kapton tape works well for
   pinning down an auxiliary board's wiring if it doesn't have its own
   mounting holes.

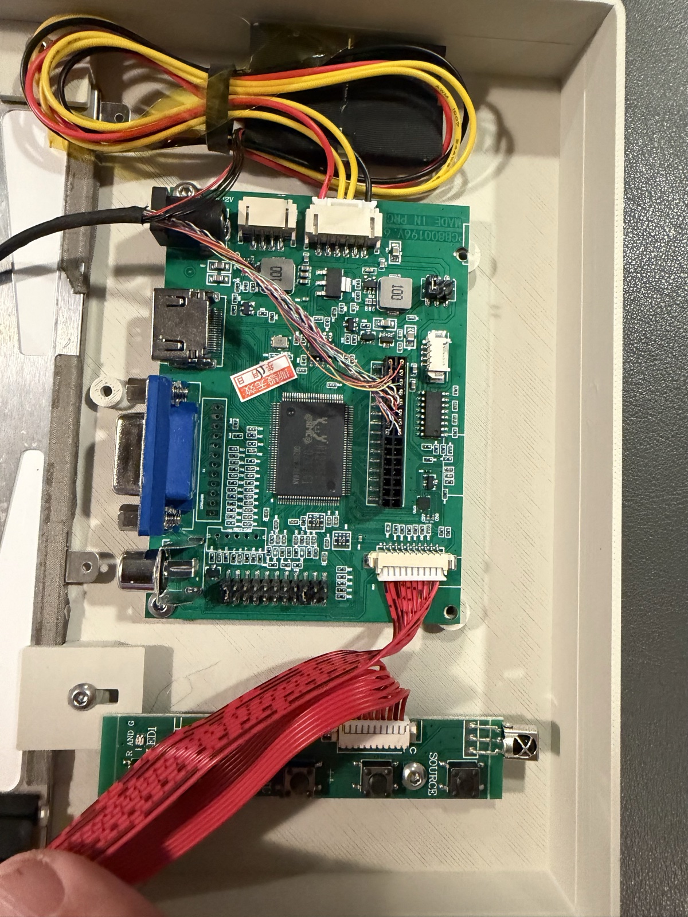
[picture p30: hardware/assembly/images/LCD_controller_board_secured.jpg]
LCD controller board secured, ribbon cable connected


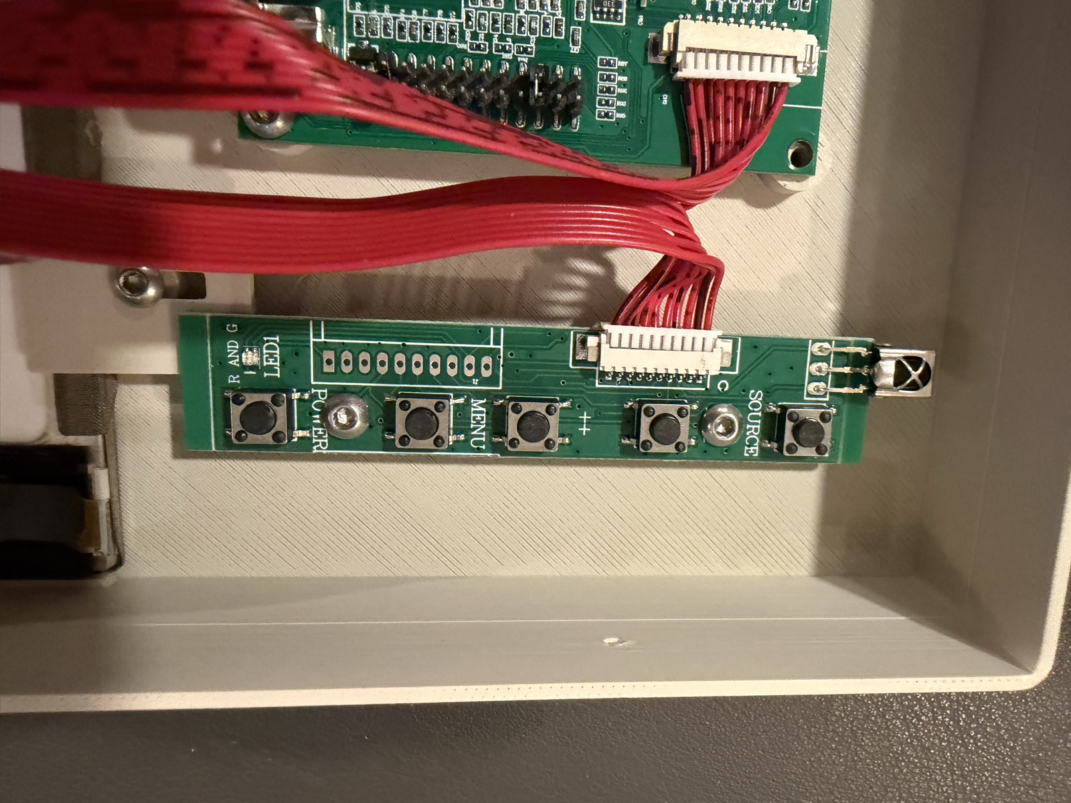
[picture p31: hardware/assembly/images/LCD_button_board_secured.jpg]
Optional button board (SOURCE/MENU/POWER) secured


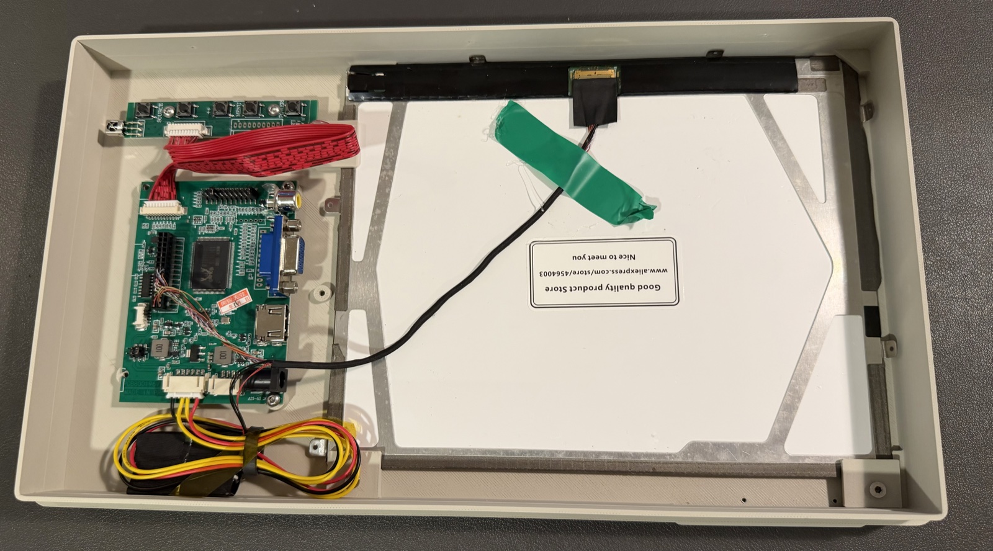
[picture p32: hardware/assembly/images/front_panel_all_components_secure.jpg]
Front piece with LCD, controller board, and button board all secured


## 8. Join the two halves and close the case

1. Bring the two wires from the back piece (HDMI, and the 12V DC power
   pigtail from step 3) up to the front piece and plug them into the
   controller board.

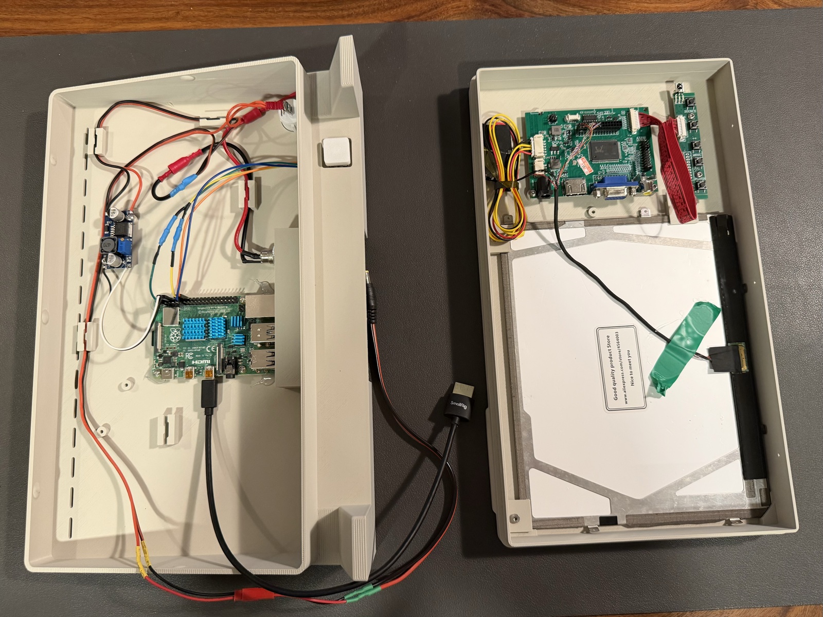
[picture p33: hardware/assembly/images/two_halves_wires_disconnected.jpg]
Back and front pieces, before connecting
   
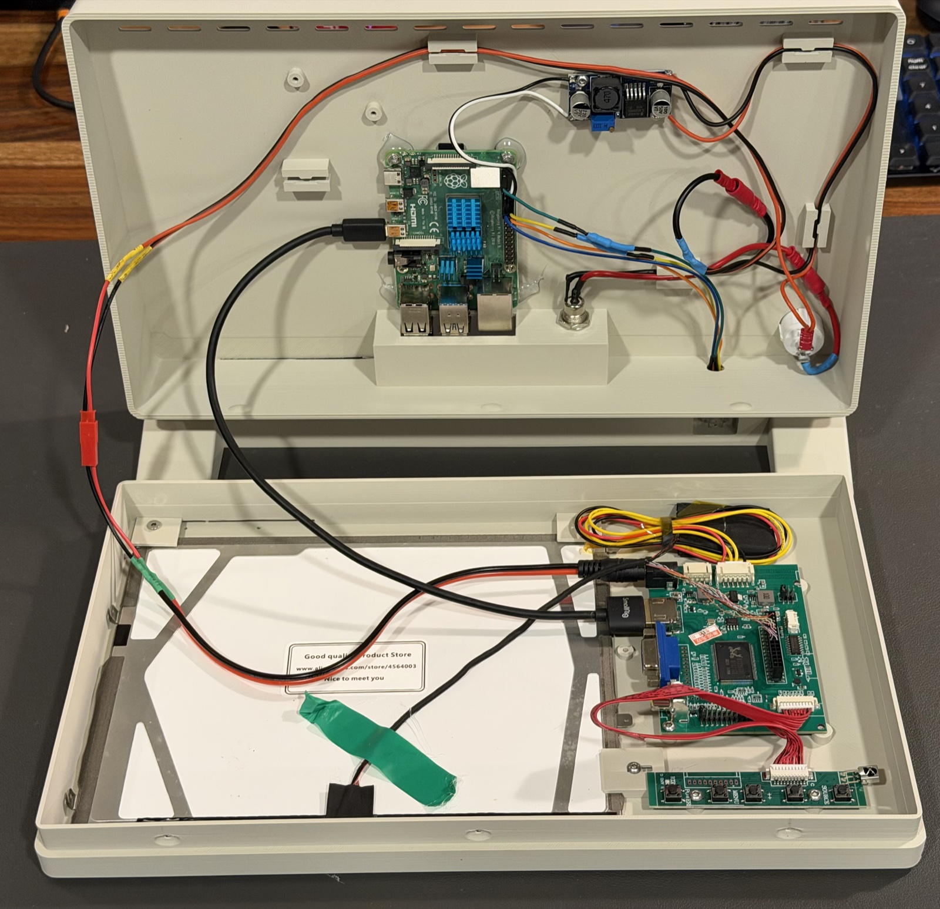
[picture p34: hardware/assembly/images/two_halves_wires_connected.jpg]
Back and front pieces, HDMI and power connected
   

2. Tuck the connected wires into the case, then press-fit the front
   piece onto the back piece. (You can also test everything before
   snapping them together — the fit comes apart easily if you need to
   get back in.)

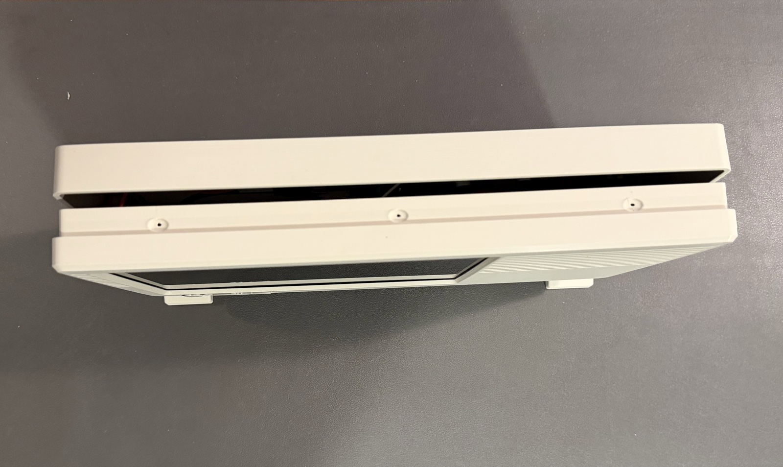
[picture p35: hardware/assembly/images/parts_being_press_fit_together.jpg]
Front and back pieces being press-fit together
   

3. Push the 3D-printed keycap over the power button switch/LED.

The unit is now fully assembled.

## 9. Power-on test

1. Plug the 12V DC power supply into the case's barrel jack input.
2. Connect a USB keyboard and mouse to the Pi.
3. Flip the rocker switch on.

Confirm it boots the way `docs/software-setup.md` §7's "Verifying the
round trip" describes (straight into the picker, no login prompt) before
buttoning up anything further.

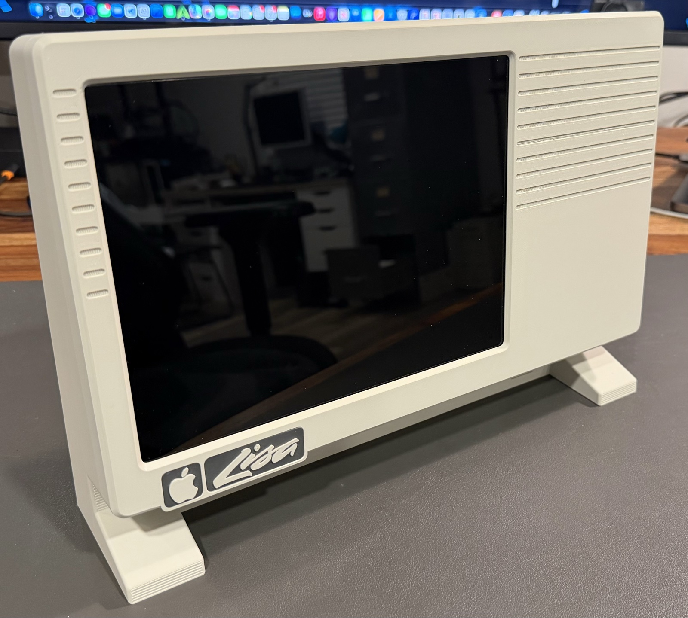
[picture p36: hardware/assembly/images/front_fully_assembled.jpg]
Fully assembled Lisa Mini Pi, booting


## Future revision being explored: iPad 3/4 panel + Pi 5 dual-power board

Not started, no build yet — noting the direction here so it's not lost.
A newly-acquired iPad 3/4 LCD + driver board
([AliExpress listing](https://www.aliexpress.us/item/3256808678954635.html))
and a Pi 5 dual-power board
([AliExpress listing](https://www.aliexpress.us/item/3256808543956539.html))
are being considered for a future revision, for two reasons:

- The iPad 3/4 panel's driver board runs on **5V** (unlike the current
  iPad 1/2 panel's 12V) and the panel's native resolution is higher than
  the current 1024x768 target - both a potential visual-quality
  improvement for LisaEm's display scaling and, since the driver board's
  input voltage would then match the Pi 5's own supply requirement, a
  possible way to power both from the same rail.
- The dual-power board comes in two input variants: a 12V barrel-jack
  version, and a 3.81mm 2-pin terminal version. The barrel-jack version
  could serve as the sole system input, but the 2-pin terminal version is
  the better fit for this project specifically, since it preserves room
  for a physical rocker power switch upstream (as in the wiring in this
  document) - and since the panel would now also run on 5V, this
  combination would let the whole system drop the 12V→5V buck converter
  entirely, powering the Pi and the LCD from the same 5V rail the dual-
  power board provides.

This would mean real changes to the wiring in this document (no buck
converter, different LCD controller power input) and likely to
`theme.py`'s fixed 1024x768 layout assumptions (see the main README's
"Project status") once a real target resolution is known - treat as new
exploration when it's picked up, not a drop-in swap of parts.

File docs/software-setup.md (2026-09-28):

# Software Setup

End-to-end setup for the software side of the Lisa Mini Pi: the patched
LisaEm build, the kiosk launcher, the physical power-button/LED wiring, and
the boot-time systemd configuration that ties it all together. Five
emulators are covered: LisaEm (§1), Basilisk II (§4), Mini vMac (§5),
Previous/NeXT (§6), and LinApple/Apple II (§7).

**`../scripts/provision.sh` automates every step below** except placing
your own ROM/disk images (never redistributed here - see each section)
and the physical GPIO wiring. This file remains the reference for what
that script does and why; read a section here if a step needs more
context than the script's own comments give, or if you're doing
something by hand instead.

**Pi 3B note (as of 2026-09-25):** only LisaEm, Basilisk II, and Mini
vMac are installed on the project's Pi 3B - it doesn't have the
power/performance headroom for Previous and LinApple as well. `config.json`
is shared/identical across both Pis (every path in it is now uniform), so
this is purely about which `.deb`s got installed where, not a config
difference. `check_deps.py` will correctly flag `next`/`apple2` as
missing on a Pi 3B set up this way - that's expected, not a bug to fix.

## 1. Apple Lisa emulation: building the patched LisaEm

The stock `arcanebyte/lisaem` has a couple of Linux/ARM-specific bugs.
`wottle/lisaem` (branch `lisa-fixes-1024x768`) carries the fixes on top of
`arcanebyte/lisaem`'s `master`, including:

- The Power Button menu item never had a working keyboard shortcut, on any
  platform — menu labels alone don't create working accelerators in this
  app, because its keyboard-capture code (`LisaWin::OnChar`/`OnKeyDown`)
  steals all keyboard input for Lisa emulation before wx's own
  menu-accelerator dispatch ever sees it. F12 and Ctrl+Alt+P are now wired
  up the same way the existing F11/zoom shortcuts already were: as
  hardcoded key checks in `OnChar`. This is what the GPIO power button
  (see below) actually presses.

### Build prerequisites

```bash
sudo apt install -y xserver-xorg xinit x11-xserver-utils openbox
```

wxWidgets 3.2.1 needs to be built from source into `/usr/local/wx3.2.1-gtk`
(the stock Raspberry Pi OS package is too old). See the upstream LisaEm
build docs for the wxWidgets build steps; once it's in place:

```bash
export PATH=/usr/local/wx3.2.1-gtk/bin:$PATH
```

### Building

```bash
git clone --branch lisa-fixes-1024x768 https://github.com/wottle/lisaem.git ~/lisaem-fixes-src
cd ~/lisaem-fixes-src
export PATH=/usr/local/wx3.2.1-gtk/bin:$PATH
./build.sh clean build
```

A full `clean build` takes roughly 10-12 minutes on a Raspberry Pi 3B.
Incremental `./build.sh build` after touching a single `.cpp` file is much
faster (a few minutes).

**Memory warning (Pi 3B, 1GB RAM):** running a full desktop session and a
build at the same time can lock the Pi up hard enough to need a physical
power cycle. Before a `clean build`, drop to a text console first:

```bash
sudo systemctl isolate multi-user.target
# ... build ...
sudo systemctl isolate graphical.target
```

An incremental single-file rebuild is light enough to usually be fine
without dropping to console, but watch `free -h` if in doubt.

The resulting binary is `~/lisaem-fixes-src/bin/lisaem`.

### Required launch environment

LisaEm must be launched with `GDK_BACKEND=x11` explicitly set. Without it,
GTK prefers native Wayland whenever `WAYLAND_DISPLAY` is set (even with
`DISPLAY` also set), which makes LisaEm's window invisible to X11 tools
like `xdotool` — which the power-button watcher depends on to send it the
F12 keypress.

## 2. GPIO power button and LED

Full pinout diagram: `hardware/pi-wiring-diagram.svg` (also covers the
buck-converter power wiring below).

Hardware wiring:

- **Pi power**: the 12V→5V buck converter's output feeds the Pi directly
  through the GPIO header — 5V into **Pin 2**, ground into **Pin 6** —
  not through the USB-C/micro-USB port. This bypasses the Pi's USB input
  protection, so the supply must be a clean, regulated 5V/3A+ source, and
  **USB power must never be connected at the same time** as GPIO power.
- **LED** (status/power indicator): 3.3V logic from GPIO18 (**Pin 12**) →
  resistor (330Ω) → LED → GND (**Pin 14**), GPIO18 driven directly as an
  output (high = on). 330Ω limits LED current to roughly 4mA at 3.3V for
  a typical LED — recalculate if using a different LED's forward voltage/
  current rating.
- **Power button switch**: 3.3V (**Pin 1**) → resistor (330Ω) → switch →
  GPIO17 (**Pin 11**), configured as an input with the internal
  pull-down enabled, so it reads a clean low when open and high when the
  switch closes (pressed).

```bash
pinctrl set 18 op dl      # LED off by default
pinctrl set 17 ip pd      # button input, pull-down
```

GPIO tooling used: `pinctrl` (state changes) and `gpiomon`/`gpiodetect`
(from `gpiod`/`libgpiod`, edge detection) — both ship with current
Raspberry Pi OS.

### `lisa-run-with-led.sh`

Launches LisaEm, turning the LED on for as long as it's running:

```bash
software/lisa-pi-launcher/lisa-run-with-led.sh -k -d
```

(`-k`: kiosk mode - power on immediately, fullscreen, quit the process
once the Lisa powers off; `-d`: boot from the ProFile/Widget drive. This
is also exactly what `config.json`'s `lisa` entry passes, so the button
and the launcher menu behave identically.)

**`-k` on the `lisa-fixes-1024x768` branch used to unconditionally force
mouse-to-top-reveals-menu off** - fine for a picker with no other UI, but
on a kiosk with no titlebar/window-manager chrome, that's the *only* way
to reach the Special/Shut Down menu without a keyboard, so it's been
patched to leave that setting at its saved default (on) instead. There's
no `-M`/`-M-` flag on this branch to fix it via the command line the way
the other `wottle/lisaem` branch used - see the patch note in
`software/lisa-pi-launcher/SETUP.md`'s Known Gaps if rebuilding from a
clean checkout of this branch.

### `lisa-power-button-watcher.sh`

A **persistent** watcher — meant to run for the entire time the Pi is on,
independent of whether the launcher menu or an emulator is currently
showing (started once, alongside `openbox`, in
`system/xsession-launcher.sh`; see below). On each GPIO17 press, it
dispatches to whichever emulator (if any) is currently running:

- **LisaEm**: sends F12 (its power-button hotkey), via `lisa-run-with-led.sh`.
- **Previous**: sends F10, its documented clean-shutdown key (§6), via
  `previous-run-with-led.sh`.
- **LinApple**: sends F12, its quit hotkey, via `linapple-run-with-led.sh`.
  User-confirmed on real hardware (2026-09-24) that this cleanly quits
  LinApple, unlike the other two below - not source-reviewed the way
  Basilisk II/Mini vMac were, since Apple II has no ADB/soft-power
  concept for F12 to map onto; it's simply LinApple's own quit binding.
- **Basilisk II and Mini vMac**: deliberately *not* handled — the button
  press is ignored while either is running. Upstream Basilisk II source
  (`src/SDL/video_sdl.cpp` in `cebix/macemu`) maps a window-close request
  to a genuine ADB Power keypress (`ADBKeyDown(0x7f)`/`ADBKeyUp(0x7f)`),
  which would be exactly what we want — **but the actual Debian-packaged
  `basilisk2` build doesn't behave this way**: confirmed on real hardware
  (2026-09-24) that neither `xdotool windowclose` nor a raw
  `WM_DELETE_WINDOW` `ClientMessage` sent directly to its actual window
  (verified correct via the full X window tree, not guessed) has any
  effect at all - the package is apparently built from an older codebase
  (its man page is dated 2002) later relinked against SDL2, whose event
  handling doesn't match the modern upstream fork's source. This fork of
  Mini vMac has no safe host-triggerable shutdown at all either (no
  signal handler, buffered disk writes only flushed on a clean exit, and
  its own force-quit path is documented by the emulator itself as a
  disk-corruption risk). Shut both of these down from inside the guest
  instead.
- **Nothing running** (the launcher menu is showing): launches LisaEm
  via `lisa-run-with-led.sh` — the button "powers on" the Lisa.

All three LED wrapper scripts (`lisa-run-with-led.sh`,
`previous-run-with-led.sh`, `linapple-run-with-led.sh`) follow the same
pattern: light GPIO18 on start, turn it off on exit (however it exits),
so the LED doubles as a visual "the power button will do something for
this emulator" indicator - deliberately not wired up for Basilisk II or
Mini vMac, matching the button itself.

**A bare `SIGTERM`/kill to any of these processes was deliberately never
considered as a shutdown mechanism** — for Mini vMac specifically it's
actively unsafe (unflushed buffered disk writes); for Basilisk II it's a
lower-risk fallback if you want it (no signal handler, but disk writes
are raw unbuffered syscalls, so the actual risk is closer to unplugging
a real un-shutdown Mac than to real data loss) but isn't wired up here by
choice; for all of them it skips the guest OS's own clean-shutdown
sequence, which is the whole
point of a power button in the first place.

Key detail: it sends the keypress via a plain, untargeted `xdotool key`
(XTEST-based), relying on LisaEm already having input focus by default as
the only real window in the kiosk session. Earlier attempts to explicitly
focus/activate the window first (`xdotool windowfocus`, `xdotool
windowactivate`) both failed with X protocol errors in this openbox-managed
session — the untargeted approach is what actually works reliably here.

## 3. The kiosk launcher

See `software/lisa-pi-launcher/README.md` and `SETUP.md` for the launcher
app itself (configuration format, controls, running it standalone for
development).

### Boot-time integration

The launcher runs as `launcher.service` (see `system/launcher.service`),
which:

- Takes over `/dev/tty1` directly (`PAMName=login`, `TTYPath=/dev/tty1`,
  `Conflicts=getty@tty1.service`) so it can start its own X session without
  needing a normal login session.
- Starts `openbox` and this project's power-button watcher, then runs
  `launcher.py` (see `system/xsession-launcher.sh`).
- `Restart=always` respawns the kiosk if it or an emulator it launched
  ever crashes out to a shell.

**Important:** this conflicts with the normal desktop (`lightdm`) for
control of `tty1` — both will crash-loop if left enabled together. The
kiosk launcher is meant to fully replace the desktop on boot:

```bash
sudo systemctl disable --now lightdm
sudo systemctl enable --now launcher.service launcher-watchdog.timer
```

`system/10-lisa-launcher-power.rules` is a polkit rule allowing the
launcher's own shutdown/reboot keys (`S`/`R`) to work without
authentication, including while a second session (e.g. an SSH login used
to administer the Pi) is also active.

## 4. Basilisk II (classic Mac OS, System 7.5.3)

Full install/build steps are in
`software/lisa-pi-launcher/SETUP.md` §4, not duplicated here. Installed
at `/usr/bin/BasiliskII` via `apt install basilisk2`, launched by the
launcher with no extra flags — see `config.json`.

**GPIO power button**: not wired up (§2 above) - the Debian-packaged
build doesn't respond to a clean window-close/ADB-power-key request the
way upstream Basilisk II's own source does (confirmed on real hardware,
2026-09-24 - see §2's watcher script notes). Shut it down from inside
the guest instead.

## 5. Mini vMac (classic Mac OS, System 6.0.8)

Full install/build steps (including the `-cpu x64`/`-ndp 1` flags and
why they're required) are in `software/lisa-pi-launcher/SETUP.md` §5,
not duplicated here. Installed at `~/minivmac-final/`, launched by the
launcher with a specific ROM and System 6 disk image — see
`config.json`.

**GPIO power button**: not wired up (§2 above) - this fork has no safe
host-triggerable shutdown at all (no signal handler; buffered disk
writes only flush on a clean exit; its own internal force-quit path is
documented by the emulator itself as a disk-corruption risk). Shut it
down from inside the guest instead.

## 6. Previous (NeXT Computer, NeXTSTEP 3.3)

Installed from a pre-built `.deb`, not built from source - the project's
GitHub/SourceForge source build needs SDL3 built from source on top of
CMake, and a pre-built package already exists for arm64:

```
curl -LO http://previous.nextcommunity.net/release/previous_4.4-0wmlive1_arm64.deb
sudo apt-get install -y ./previous_4.4-0wmlive1_arm64.deb
```

This pulls in `libsdl3-0` and the rest of its dependencies from Debian's
own repos automatically - no manual SDL3 build needed. The package also
**bundles NeXT ROM images** (`/usr/share/previous/Rev_3.3_v74.BIN`,
etc.) - no separate ROM sourcing required, unlike LisaEm/Basilisk
II/Mini vMac.

Previous has **no command-line flags at all** - `previous.1`'s man page
says so explicitly. Everything (machine type, ROM selection, boot
options, disk images, fullscreen) is configured interactively via an
in-app settings GUI (press **F12** while it's running), saved to
`~/.config/previous/previous.cfg`, and reloaded automatically on every
subsequent launch.

`config.json`'s `next` entry runs `previous-run-with-led.sh` (no
arguments) rather than `/usr/bin/previous` directly - it's the same
LED-on/LED-off wrapper pattern as `lisa-run-with-led.sh` for LisaEm,
lighting GPIO18 for as long as Previous is running so the LED signals
"the power button will do something" (the watcher sends Previous F10 -
see §2's `lisa-power-button-watcher.sh` section). The one-time
interactive setup below has to happen at the physical Pi (keyboard
required for a couple of steps) regardless of which of the two you
launch it with.

You'll need a NeXTSTEP disk image - not redistributed here. One-time
setup, at the Pi, with a keyboard attached:

1. Launch Previous from the picker (or run `/usr/bin/previous` directly
   for this first-run setup - the LED wrapper isn't required for setup,
   just for the LED). The settings GUI opens automatically on first
   launch.
2. Uncheck **Show at startup** - see the gotcha below, this alone isn't
   enough.
3. **System settings → Machine Type**: `NeXTstation` (not Turbo, not
   color) gave the best performance on a Pi 4.
4. **Boot Options**: set Boot device to `SCSI disk`; uncheck both
   `SCSI tests` and `Verbose test mode`.
5. **SCSI Disks**: add your NeXTSTEP disk image as `SCSI Disk 0`.
6. Click **Save config** (not just OK) to persist these to
   `~/.config/previous/previous.cfg`.
7. NeXTSTEP will pause waiting for a network config server (Ethernet
   isn't emulated) - press **Ctrl-C** to continue booting past that.
8. To shut down cleanly from inside NeXTSTEP, press **F10** (not a
   guest-OS shutdown menu item).

**Gotcha confirmed on real hardware (2026-09-23):** unchecking "Show at
startup" in the GUI and clicking Save config does *not* reliably persist
that one setting - the config dialog kept reopening on every launch
regardless. Previous has no command-line flag to suppress it either (the
man page is explicit: no CLI flags at all). Fix it directly in the saved
config file instead:

```
sed -i 's/^bShowConfigDialogAtStartup = TRUE/bShowConfigDialogAtStartup = FALSE/' ~/.config/previous/previous.cfg
```

After that, `previous.cfg` remembers everything (machine type, boot
options, disk path) and later launches from the picker boot straight
into NeXTSTEP with no dialog and no F12 needed - only the disk path
changes if you move the `.dd`/image file.

A separate, unexplained wrinkle also showed up during initial setup on a
Pi 4: launching `/usr/bin/previous` directly from the picker (via
`subprocess.run`, no wrapper) reliably exited after almost exactly 3
seconds *before* `previous.cfg` existed at all, with no crash/error in
its output - reproducible standalone via SSH too regardless of
`start_new_session`/env vars, but never once it had a saved config to
load. Once `previous.cfg` exists (from the one-time setup above),
launching it directly is stable. If this ever recurs on a fresh Pi,
deleting `~/.config/previous/` and redoing the one-time setup is the
known trigger to watch for, not something to chase as a launcher bug
first.

## 7. LinApple (Apple II / II+ / //e)

Installed from a pre-built `.deb` (github.com/linappleii/linapple
releases, an actively-maintained project - not the older abandoned
"linapple-pie" fork, whose changes have been merged upstream here):

```
curl -LO https://github.com/linappleii/linapple/releases/download/v3.0-beta-3/linapple-v3.0-beta-3-linux-arm64.deb
sudo apt-get install -y ./linapple-v3.0-beta-3-linux-arm64.deb
```

**Bundles its own Apple II ROMs** (built in, not separate files) - no
ROM sourcing needed at all, unlike every other emulator in this project.

### Two packaging gotchas on arm64/trixie (both confirmed 2026-09-23)

This is a beta release and its arm64 `.deb` has real packaging bugs on
current Debian trixie - both needed a manual fix after `apt-get install`
otherwise succeeded:

1. **`libSDL3_image.so.0` isn't even declared as a dependency**, despite
   the binary needing it. Install it separately:
   ```
   sudo apt-get install -y libsdl3-image0
   ```
2. **The binary is linked against `libzip.so.4`, which doesn't exist on
   trixie** (renamed to `libzip.so.5` - the `.deb`'s declared
   `libzip4 | libzip-dev` dependency lets `apt` install `libzip-dev`
   instead, which satisfies the *packaging* dependency check but not the
   actual *runtime* linker, since `libzip-dev` doesn't ship the old
   soname either). A compatibility symlink fixes it - libzip's C API
   (`zip_open`/`zip_fopen`/`zip_fread`/etc.) has stayed stable across its
   soname bumps for years, so this is low-risk despite looking hacky:
   ```
   sudo ln -sf /usr/lib/aarch64-linux-gnu/libzip.so.5.5 /usr/lib/aarch64-linux-gnu/libzip.so.4
   sudo ldconfig
   ```

Verify both are fixed with `ldd /usr/bin/linapple | grep "not found"` -
it should print nothing.

### Total Replay (a ready-to-boot game library)

[Total Replay](https://archive.org/details/TotalReplay) is a single
ProDOS hard-disk image (`.hdv`) bundling hundreds of native Apple II
games behind a menu - much more convenient for a kiosk than sourcing
individual floppy images:

```
curl -L -o ~/TotalReplay_v6.1.hdv "https://archive.org/download/TotalReplay/Total%20Replay%20v6.1.hdv"
```

`config.json`'s `apple2` entry launches straight into it via
`linapple-run-with-led.sh` (§2's LED wrapper), forwarding all arguments
to the real binary:
```
["/home/wottle/lisa-mini-pi/software/lisa-pi-launcher/linapple-run-with-led.sh", "--hd1", "/home/wottle/TotalReplay_v6.1.hdv", "--autoboot", "--fullscreen"]
```

`linapple --help` lists the full flag set if you want a different boot
disk/hard disk instead - `-1`/`-2` for floppy drives 1/2, `--hd1`/`--hd2`
for hard disks (Slot 7), `-a`/`--autoboot`, `-f`/`--fullscreen`.

## 8. Custom boot splash

Raspberry Pi OS's boot splash (the image shown between the rainbow-square
firmware screen and the kiosk actually starting) is Plymouth, using the
stock `pix` theme. That theme's script
(`/usr/share/plymouth/themes/pix/pix.script`) auto-scales and centers
whatever `splash.png` it finds in its own theme directory to fit the
actual connected display — so `software/boot-splash/splash.png` doesn't
need to exactly match any particular panel's resolution, just its
approximate aspect ratio (it's 1448x1086, 4:3, matching the 1024x768
target panel).

```
sudo software/boot-splash/install.sh
sudo reboot
```

The script backs up the stock image to
`/usr/share/plymouth/themes/pix/splash.png.orig` (once — it won't
overwrite an existing backup) before installing the custom one, and runs
`update-initramfs -u` afterward, which is required on current Raspberry
Pi OS (`auto_initramfs=1` in `/boot/firmware/config.txt`) — Plymouth
reads its theme files out of the initramfs image at early boot, not
directly off the live root filesystem, so a plain file copy alone
doesn't take effect until the initramfs is rebuilt.

It also idempotently adds `splash`, `quiet`, and
`plymouth.ignore-serial-consoles` to `/boot/firmware/cmdline.txt` if
they're missing — confirmed on real hardware (2026-09-27) that without
`splash`/`quiet`, Plymouth never engages at all and boot just shows raw
kernel/systemd text instead of this image, and separately that Plymouth
disables its graphical splash whenever it detects a serial console
(`console=serial0,115200`, part of this cmdline by default), which is a
sensible default for a headless Pi but wrong for this kiosk.

To revert to the stock Raspberry Pi splash:

```
sudo cp /usr/share/plymouth/themes/pix/splash.png.orig /usr/share/plymouth/themes/pix/splash.png
sudo update-initramfs -u
```

### Disabling the rainbow firmware splash

Before Plymouth (or even Linux) starts, the Pi's GPU firmware briefly
shows a rainbow-square diagnostic test pattern. That screen is rendered
directly by the firmware, not from an image file, so there's no supported
way to replace it with custom art — only to skip it. Add this to
`/boot/firmware/config.txt`, in the global section above the
`[cm4]`/`[cm5]`/`[pi5]` platform-specific sections (e.g. right after
`arm_boost=1`):

```
disable_splash=1
```

With it set, boot goes straight from a brief black screen into the
Plymouth splash above instead of showing the rainbow test pattern first.

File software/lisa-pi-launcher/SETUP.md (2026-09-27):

# Setting Up a New Pi

Step-by-step instructions for provisioning a brand-new Raspberry Pi with
this whole stack: the boot kiosk launcher plus LisaEm, Basilisk II, and
Mini vMac. This is a **living document** — when a step here turns out to
be wrong, incomplete, or unnecessary, fix it in the same change that
changes the actual setup. Don't let this drift from what a fresh Pi
actually needs.

**`../../scripts/provision.sh` automates all five emulators**, not just
the three this file covers - it's the faster path for a fresh Pi. This
file (and `../../docs/software-setup.md`) remain the reference for what
that script does and why.

**This file does not cover Previous (NeXT) or LinApple (Apple II) at
all** - those were added later and are documented only in
`../../docs/software-setup.md` §6-7, including their real
packaging/dependency gotchas on Debian trixie. If you're setting up a
system with all five emulators, read that file, not this one, for the
last two.

This directory (`software/lisa-pi-launcher/`) lives inside the
[`lisa-mini-pi`](../../README.md) umbrella repo. This file covers the
launcher app itself in detail; `../../docs/software-setup.md` is the
project-wide walkthrough (LisaEm build, GPIO power-button/LED wiring, and
how this directory fits into the boot-time systemd setup) - read that one
first if you're setting up a Pi from scratch. **These two docs currently
overlap in places and haven't been fully reconciled** - if you find a
contradiction between them, the more specific/recently-updated one is
probably right; fix the other one to match.

Every command below runs as a normal user over SSH unless marked
`(sudo)`. `sudo` commands need to be run interactively by a human, not by
an agent — an agent should hand you the exact command rather than run it.

## Hardware

- Raspberry Pi 4 Model B (a Pi 5 also works the same way for everything
  in this file — same 64-bit Debian "trixie" OS image, same apt packages,
  same build steps. The one Pi-4-specific item in this repo is the
  `vc4_hvs` kernel warning noted in §7's Known Gaps for the desktop↔kiosk
  switch on a Pi 4 + this project's HDMI panel; that hasn't been tested
  on a Pi 5, since Pi 5 uses a different display driver stack).
- microSD card (boot media)
- The final target display is a 1024x768 HDMI LCD panel (a repurposed
  iPad 2 panel + HDMI driver board) — a Lisa-shaped 3D-printed case is
  built around it. Everything in this repo that's "sized for the real
  display" means 1024x768, even while testing on a different monitor.
- USB keyboard/mouse
- A second computer with [Raspberry Pi Imager](https://www.raspberrypi.com/software/)
  installed and a microSD card reader (built-in or USB), to flash the card
  before it ever goes in the Pi.

The physical GPIO power-button/LED wiring isn't covered in this file —
see `../../docs/software-setup.md` §2, and
`../../hardware/pi-wiring-diagram.svg` for the full pinout (buck
converter power, switch, LED).

## 1. Flash the OS

1. Insert the microSD card into your computer's reader and open Raspberry
   Pi Imager.
2. **Choose Device** → your Pi model (**Raspberry Pi 4** or **Raspberry
   Pi 5**).
3. **Choose OS** → **Raspberry Pi OS (64-bit)** — this is in the top-level
   list, not under "Raspberry Pi OS (other)". Current release (Debian
   "trixie"-based as of this writing) — the **full Desktop image**, not
   Lite. (The kiosk itself doesn't need a desktop environment — see §5 —
   but Basilisk II's apt package and this guide's dependencies assume the
   full image's repositories/desktop-adjacent packages are available.
   Lite hasn't been tested with this setup.)
4. **Choose Storage** → your microSD card. Double-check you've picked the
   card and not another drive — this step erases whatever's selected.
5. Click **Next**. The Imager will ask "Would you like to apply
   OS customisation settings?" — click **Edit Settings** (this is the
   gear-icon/Ctrl-Shift-X panel from older Imager versions, just presented
   as a prompt now). Set, across its **General** and **Services** tabs:
   - **General tab**: hostname (e.g. `lisa-pi.local`), username/password,
     Wi-Fi SSID/password if the Pi won't be on Ethernet, locale/timezone/
     keyboard layout.
   - **Services tab**: toggle **Enable SSH** on, then choose either
     "Use password authentication" or "Allow public-key authentication
     only" (paste your public key if so). Password auth is simplest for
     a first-time setup; switch to key-only later if you want.
   - Click **Save**, then confirm you want to apply these settings when
     prompted.
6. Click **Yes** to begin writing, then **Yes** again to confirm erasing
   the card. Wait for the write + verify to finish (a few minutes).
7. Move the card to the Pi, connect Ethernet or rely on the Wi-Fi
   credentials set above, and power it on. First boot (partition resize,
   first-run services) can take a minute or two longer than later boots —
   give it 2-3 minutes with no keyboard/monitor needed before trying to
   connect.
8. SSH in from your computer. SSH is just a way to type commands on the
   Pi from your computer's own keyboard, over the network, instead of
   plugging a keyboard/monitor into the Pi directly. Steps below are for
   macOS (Windows: use the similarly-named "Terminal" app or PowerShell,
   same `ssh` command; Linux: same as macOS).
   1. Open the **Terminal** app: press **Cmd+Space**, type `Terminal`,
      press **Return**.
   2. Type this, replacing `<user>` with the username you set in step 5
      and `<hostname>` with the hostname you set in step 5 (e.g. if you
      used username `pi` and hostname `lisa-pi`, type exactly
      `ssh pi@lisa-pi.local`), then press **Return**:
      ```
      ssh <user>@<hostname>.local
      ```
   3. The first time you connect to any new device, Terminal will show a
      warning like `The authenticity of host ... can't be established`
      and ask `Are you sure you want to continue connecting?`. This is
      expected — type `yes` and press **Return**. You won't see this
      warning again for this Pi.
   4. It will then ask for the password you set in step 5. Type it and
      press **Return** — **nothing will appear on screen as you type**,
      not even dots. That's normal terminal behavior, not a bug; just
      type the full password and hit Return.
   5. Success looks like your prompt changing to something like
      `<user>@<hostname>:~ $` — you're now typing commands on the Pi
      itself. Every command in the rest of this guide runs here, not on
      your own computer.
   - **If it hangs or says `Could not resolve hostname` / `Operation timed
     out`**: the Pi is probably still booting, or `.local` name lookup
     isn't working on your network. Wait another minute and retry the
     same command. If it still fails after a few tries, find the Pi's IP
     address instead — check your Wi-Fi router's admin page for a list of
     connected devices (look for the hostname you set), then use that
     numeric address in place of `<hostname>.local`, e.g.
     `ssh pi@192.168.1.42`.
   - **If you see `WARNING: REMOTE HOST IDENTIFICATION HAS CHANGED!`**
     (with "someone could be eavesdropping on you" below it): this is
     expected, not an attack, if you're re-flashing a Pi you've connected
     to before under the same hostname — a fresh install generates a new
     SSH host key. Remove the stale one and reconnect:
     ```
     ssh-keygen -R <hostname>.local
     ssh <user>@<hostname>.local
     ```
     then answer `yes` to the new host-key prompt as in step 3 above.

## 2. Base packages

```
sudo apt update
sudo apt install -y git build-essential python3-pip python3-venv \
  python3-pygame python3-pil \
  basilisk2 \
  openbox \
  libx11-dev x11-utils
```

- `basilisk2` is the apt package for Basilisk II — no source build
  needed.
- `python3-pygame`/`python3-pil` are used directly (system packages, not
  a venv) by the launcher on the Pi — see §6.
- `openbox` brokers window-focus handoff in the kiosk X session (see
  §5 for why a window manager is needed at all).

## 3. LisaEm

Built from source — this project's own fork
(`https://github.com/wottle/lisaem`), branch **`lisa-fixes-1024x768`**,
which has a real upstream Linux/ARM portability fix (`typedef char sint8`
is unsigned on Linux/ARM but signed on macOS/x86, breaking every backward
branch displacement in the 68k core — fixed to `typedef signed char
sint8`), several UX enhancements (kiosk `-k` flag, hotkeys, Fill/Fit
display modes), and the F12 power-button hotkey that the GPIO power
button/LED watcher (`docs/software-setup.md` §2) depends on. Don't build
the unmodified upstream `arcanebyte/lisaem`, and don't omit the branch —
this fork's default branch doesn't have these fixes.

```
git clone --branch lisa-fixes-1024x768 https://github.com/wottle/lisaem.git ~/lisaem-fixes-src
```

LisaEm needs wxWidgets 3.2.1 built from source (Debian's packaged wx is
typically older/incompatible). This also needs `libgtk-3-dev` — GTK's
development headers, not just the runtime libraries already on the
system — which isn't installed by §2's base-package list above; without
it, `configure --with-gtk` below fails to find GTK at all:

```
sudo apt install -y libgtk-3-dev
```

Then build wxWidgets itself into `/usr/local/wx3.2.1-gtk`
(`/usr/local/wx3.2.1-gtk/bin` must be on `PATH` before building LisaEm):

```
mkdir -p ~/wx-build
cd ~/wx-build
curl -L https://github.com/wxWidgets/wxWidgets/releases/download/v3.2.1/wxWidgets-3.2.1.tar.bz2 \
  -o wxWidgets-3.2.1.tar.bz2
tar xjf wxWidgets-3.2.1.tar.bz2
cd wxWidgets-3.2.1
mkdir build-gtk
cd build-gtk
CFLAGS="-fPIC" CXXFLAGS="-fPIC" ../configure \
  --with-gtk --enable-unicode --disable-debug --disable-shared \
  --without-expat --disable-richtext \
  --with-libpng=builtin --with-libjpeg=builtin --with-libtiff=builtin --with-libxpm=builtin \
  --prefix=/usr/local/wx3.2.1-gtk
make -j"$(nproc)"
sudo make install
```

This step alone can take a while (dozens of minutes depending on the
Pi) — it's compiling all of wxWidgets from source. Then build LisaEm
itself:

```
export PATH=/usr/local/wx3.2.1-gtk/bin:$PATH
cd ~/lisaem-fixes-src
./build.sh clean build
```

**Hardware note learned the hard way:** running a full desktop session
and a source build at the same time can lock up a memory-constrained Pi
(swap thrashing, unresponsive to SSH). Not generally an issue on a Pi 4
with adequate RAM, but if the build hangs, check `free -h` and consider
dropping to `multi-user.target` for the build.

You'll need a Lisa ROM (`boot.ROM`) and a Lisa Office System disk image
(a `.dc42` file, e.g. `lisaem-widget.dc42`) — these aren't redistributed
here; place them at `~/boot.ROM` and `~/lisaem-widget.dc42` (or update
`config.json`'s `lisa` entry to point elsewhere). LisaEm's own
`~/.lisaem`/`~/lisaem.conf` prefs files get created/updated by LisaEm
itself on first run and on every settings change.

**Confirmed-working asset note (2026-09-26):** the disk image must be a
bootable ProFile/Widget hard-disk `.dc42` image, matched to the `-d`
(boot hard disk) flag `lisa-run-with-led.sh` passes — a set of individual
LOS installer floppy `.image` files (e.g. one named like `LOS 3.1
1.image` through `5.image`) is **not** a substitute; those would need an
actual from-floppy OS install onto a blank hard-disk image first, which
this guide doesn't cover. If copying assets from a Mac, from a **second,
separate Terminal window on the Mac** (not the Pi's SSH session — `scp`
pushes from local to remote):
```
scp /path/to/boot.ROM <user>@<pi-hostname>.local:~/boot.ROM
scp /path/to/lisaem-widget.dc42 <user>@<pi-hostname>.local:~/lisaem-widget.dc42
```

**Placing the files is not enough — LisaEm doesn't auto-discover
`~/boot.ROM`/`~/lisaem-widget.dc42` by filename convention.** After first
run, `~/lisaem.conf` exists with `ROMFILE=` empty and
`[parallelport] path=lisaem-profile.dc42` (LisaEm's own compiled-in
default, which won't exist on your Pi). You must point these at your
actual files — trying to boot before doing this shows LisaEm's default
skin UI with a "no ROM" warning instead of powering on:
```
sed -i 's|^ROMFILE=.*|ROMFILE=/home/<user>/boot.ROM|' ~/lisaem.conf
sed -i 's|^path=lisaem-profile.dc42|path=/home/<user>/lisaem-widget.dc42|' ~/lisaem.conf
```

**If an *existing/pre-installed* Lisa Office System disk image fails to
boot with `Error 10738`** ("Checksum failure or too many hardware config
changes" — a genuine Lisa OS error, see
`~/lisaem-fixes-src/src/lisa/motherboard/los-error-codes.c`), the disk
image was "married" to a different hardware identity than this LisaEm
instance's default one. `~/lisaem.conf`'s freshly-created `serialnumber=`
and `[pram]` block are just placeholders (`ff000000...`, all-zero PRAM) —
if the disk was previously used with a different LisaEm/real Lisa, its
OS remembers *that* identity and rejects a mismatched one. Fix by copying
the exact `serialnumber=` line and `[pram]` block from whatever
LisaEm instance the disk image already boots successfully on into this
Pi's `~/lisaem.conf` (leave `ROMFILE`/`[parallelport] path` as your
Pi-local paths — only `serialnumber` and `[pram]` need to match). This
only applies to reusing an already-installed disk image; a truly blank
image installed fresh from floppies establishes its own identity on
first boot and won't hit this.

**Confirmed real bug (2026-09-26) in this fork's `-k` flag: it doesn't
actually turn off LisaEm's skin UI**, despite the docs above describing
`-k` as fullscreen+skinless+power-on+quit-on-shutdown. Root cause, in
`~/lisaem-fixes-src/src/host/wxui/lisaem_wx.cpp`: `wxCmdLineSwitchState`
is `OFF=-1, NOT_FOUND=0, ON=1` (see
`/usr/local/wx3.2.1-gtk/include/wx-3.2/wx/cmdline.h`), but `-k`'s handler
(line ~3564) sets `on_start_skin = 0;` — the *NOT_FOUND* sentinel, not
`wxCMD_SWITCH_OFF` (-1) — so the downstream `if (on_start_skin ==
wxCMD_SWITCH_OFF)` check (line ~3468) never fires and the skin setting
just falls through to whatever `~/.lisaem` has saved. (The fullscreen
half of `-k` sets `on_start_fullscreen = 1`, which correctly matches
`wxCMD_SWITCH_ON` — only the skin toggle is affected.) Not yet patched
upstream in the fork. **Workaround**: write these known-working values
directly into `~/.lisaem` (confirmed on real hardware, both Pi 4 and Pi
5) rather than relying on `-k` to set them:
```
cat > ~/.lisaem <<'EOF'
hidpi_scale=100
soundeffects=1
displayskins=0
displaymode=6
centerskinless=1
asciikeyboard=1
lisaconfigfile=/home/<user>/lisaem.conf
throttle=16
emutime=40
emutick=25
hostrefreshrate=0
forcerefresh=0
use_mouse_scale=0
hidehostmouse=1
disable_screen_dimming=1
mousetopmenufullscreen=0
[lisawin]
sizey=768
sizex=1024
[lisaframe]
sizey=768
sizex=1024
fullscreen=1
[lisaskin]
name=default
EOF
```
(`displayskins=0` + `displaymode=6` is the skinless "Fill" video mode
that fills the real 1024x768 panel; `throttle=16`/`hidehostmouse=1`/
`disable_screen_dimming=1` are the project's own tuned values for a
dedicated kiosk display, not required just to fix the skin issue.)

## 4. Basilisk II

Already installed via apt (§2). You need a 68k Mac ROM and a classic Mac
OS disk image — these aren't redistributed here. Place them and edit
`~/.config/BasiliskII/prefs` (created on first run) to point at them.
**Confirmed-working filenames (2026-09-26):** a Mac LC III ROM as
`mac-lciii.rom` and a System 7.5.3 disk image as `macos753.image` — any
68k ROM/disk image works in principle, but these are the exact names this
example config below assumes. From a **second, separate Terminal window
on your Mac** (not the Pi's SSH session):
```
scp /path/to/your-mac-rom.rom <user>@<pi-hostname>.local:~/mac-lciii.rom
scp /path/to/your-macos-disk.image <user>@<pi-hostname>.local:~/macos753.image
```

```
rom /home/<user>/mac-lciii.rom
disk /home/<user>/macos753.image
screen dga/1024/768
displaycolordepth 0
ramsize 33554432
cpu 3
fpu false
nogui true
jit false
```

**`screen dga/1024/768`, not `win/1024/768`** — `win` just opens a plain
floating 1024x768 window (no fullscreen, no centering), which looks like
it's overlaying the desktop instead of replacing it. `dga` uses the
legacy X11 DGA extension for genuine exclusive fullscreen, and takes
over the *actual* live display resolution regardless of the configured
size, so it should adapt correctly once the real 1024x768 panel is
connected. (`dga` was avoided earlier in this project after a crash —
that crash turned out to be an unrelated process-group signal bug in the
launcher, since fixed; see the "Wiring it into the launcher" section.)

## 5. Mini vMac

**Do not use the official gryphel.com release (36.04).** It has zero
Apple Partition Map awareness — any real (partitioned) HD image gets
handed to the guest ROM at the wrong byte offset and rejected as
invalid media, even though the file opens and "inserts" successfully at
the host level. Build from
**[erichelgeson/minivmac](https://github.com/erichelgeson/minivmac)**
instead, which adds real partition-map parsing.

```
git clone https://github.com/erichelgeson/minivmac.git ~/minivmac-erich
cd ~/minivmac-erich
gcc -o setup_t setup/tool.c
./setup_t -t xgen -cpu x64 -m II -ndp 1 -fullscreen 1 \
  -hres 512 -vres 342 -mf 2 -magnify 1 > setup.sh
bash setup.sh
mkdir -p bld
# the generated Makefile's mk_COptions is missing include paths on this
# fork - add them (and -g for debuggability) before building:
sed -i 's/mk_COptions = -c$/mk_COptions = -c -g -Icfg\/ -Isrc\//' Makefile
make
```

**Expected, harmless noise:** `bash setup.sh` prints
`setup.sh: line 520: -Icfg/: No such file or directory` (line number may
vary) partway through. Confirmed (2026-09-26, Pi 5) that this doesn't
stop `setup.sh` from finishing or writing a usable Makefile — `make`
right after picks up the `sed`-patched include paths correctly and
produces a working `minivmac` binary. Don't stop and troubleshoot this
line on its own; only worry if `make` itself fails afterward.

Flag notes (all found by reading this fork's `setup/*.i` sources, not
guessed):
- `-t xgen`: "Generic X11" target. There is no dedicated 64-bit-ARM
  target in this 2018-era codebase (`-t larm` is 32-bit ARM only) —
  `xgen` is architecture-neutral and confirmed working.
- `-cpu x64`: **required**, and not obvious from the flag name. This
  codebase's internal "4-byte Long" type (`ui5b`) is `unsigned int` only
  when `-cpu x64` is selected; otherwise it falls back to `unsigned
  long`, which is 8 bytes on 64-bit Linux/ARM. That mismatch causes real
  heap-buffer overruns (`SetLongs`/`ReserveAllocOneBlock`) and a broken
  32-bit CRC in the video card's slot-ROM checksum routine, which makes
  the real Mac II ROM reject the emulated video card outright (black
  screen forever, CPU/interrupts running fine). Confirmed via `gdb`
  against a live process — not a theoretical concern.
- `-m II`: Mac II model (matches a Mac II ROM — see below).
- `-ndp 1`: `NonDiskProtect`, this fork's Apple Partition Map parser —
  the actual fix for the disk-rejection problem above.
- `-hres 512 -vres 342 -mf 2 -magnify 1`: native compact-Mac resolution
  (512x342), magnified 2x (1024x684) and started already magnified —
  sized for the real 1024x768 target panel (684 leaves ~84px total
  letterboxing top/bottom, since 512:342 isn't quite 4:3). On any bigger
  test monitor this will appear smaller/centered with black borders —
  expected, not a bug; it'll fill correctly on the real panel.

You'll need a Mac II ROM and a System 6-or-later disk image with a real
Apple Partition Map (a plain unpartitioned raw image also works, just
doesn't need `-ndp`). Place them and point `config.json`'s `command` at
them. **Confirmed-working filenames (2026-09-26):** `MacII.ROM` and a
partitioned hard-disk image named `System6.image` (a real System 6.0.8
HD image, not a plain floppy image):

```
mkdir -p ~/minivmac-final
cp ~/minivmac-erich/minivmac ~/minivmac-final/minivmac
```

Then, from a **second, separate Terminal window on your Mac** (not the
Pi's SSH session — `scp` pushes from local to remote):
```
scp /path/to/your-mac-ii.rom <user>@<pi-hostname>.local:~/minivmac-final/MacII.ROM
scp /path/to/your-system6.image <user>@<pi-hostname>.local:~/minivmac-final/System6.image
```

## 6. The launcher itself

```
git clone https://github.com/wottle/lisa-mini-pi.git ~/lisa-mini-pi
```

**Don't run `gen_icons.py`** — despite its own comment suggesting it's a
harmless one-time step, it unconditionally overwrites
`icons/{lisa,macintosh,next,apple2}.png` with basic procedurally-drawn
placeholders, destroying the real committed icon art (confirmed on real
hardware, 2026-09-27 — a fresh clone's real icons got clobbered down to
~150-byte placeholders after running it). Its other output, the
boot-diagnostic icons, is for `boot_diag.py`, a feature the 2026-09-25
"CHOOSE YOUR ADVENTURE" redesign no longer uses at all. Only run it by
hand if you're intentionally regenerating placeholder art from scratch.

No venv on the Pi — it runs against the system `python3-pygame`/
`python3-pil` installed in §2. Edit `config.json` to point each system's
`command` at the binaries/ROMs/disks placed in §3-5.

## 7. Kiosk session integration

**Why a window manager at all:** a bare X11 session with no window
manager was tried first and caused real bugs — keyboard focus doesn't
reliably transfer to a newly-launched emulator's window, or back to the
picker after the emulator closes, with nothing to broker that handoff.
**Openbox**, not matchbox — matchbox (tried second) doesn't correctly
implement EWMH `_NET_WM_STATE_FULLSCREEN`, which broke LisaEm's F11
leave-fullscreen (it flipped LisaEm's internal state but never actually
resized the window).

```
mkdir -p ~/.config/openbox
cp /etc/xdg/openbox/rc.xml ~/.config/openbox/rc.xml
```

Then add a rule forcing every window undecorated (no titlebars — matches
the no-window-manager look), just before `</applications>` in that file:

```xml
  <application class="*">
    <decor>no</decor>
  </application>
```

Rather than hand-editing XML, this script (idempotent — safe to re-run,
won't duplicate the rule) does the insertion for you:

```
python3 - <<'PYEOF'
import pathlib
path = pathlib.Path.home() / ".config/openbox/rc.xml"
text = path.read_text()
rule = '  <application class="*">\n    <decor>no</decor>\n  </application>\n'
if 'class="*"' not in text:
    text = text.replace("</applications>", rule + "</applications>")
    path.write_text(text)
    print("Rule inserted.")
else:
    print("Rule already present, skipped.")
PYEOF
```

Copy the systemd units and polkit rule from this repo's `system/`
directory, then enable them **(sudo)**:

```
sudo cp system/launcher.service system/launcher-watchdog.service \
  system/launcher-watchdog.timer /etc/systemd/system/
sudo cp system/10-lisa-launcher-power.rules /etc/polkit-1/rules.d/
sudo systemctl daemon-reload
sudo systemctl enable --now launcher.service
sudo systemctl enable --now launcher-watchdog.timer
```

- `launcher.service` runs `xinit` → `system/xsession-launcher.sh`
  (starts openbox, then `python3 launcher.py`) on `tty1`. It needs
  `PAMName=login` + `TTYPath=/dev/tty1` + `TTYReset`/`TTYVHangup`/
  `TTYVTDisallocate=yes` + `Conflicts=getty@tty1.service` — a bare
  `Type=simple` unit has no logind session, and Xorg fails immediately
  with `xf86OpenConsole: Switching VT failed` without one.
- `launcher-watchdog.timer` runs `launcher-watchdog.sh` every 30s, which
  restarts `launcher.service` if neither the launcher nor a known
  emulator process is running — covers the case where an emulator hangs
  on guest shutdown instead of exiting (an observed upstream quirk in
  both LisaEm and Basilisk II, not fully preventable from the launcher
  side) or the X session dies without the launcher process itself
  exiting. **Update `launcher-watchdog.sh`'s process list whenever
  `config.json` gains a new emulator binary name.**
- `10-lisa-launcher-power.rules` is a polkit rule letting the launcher's
  `S`/`R` keys (`systemctl poweroff`/`reboot`) run without a password
  prompt for the kiosk user, and letting `Q` and the desktop's "back to
  kiosk" icon start/stop the three specific units below without one
  either.

Reboot and confirm it boots straight into the picker with no login
prompt, no desktop flash, and that Escape/Ctrl+C don't get you out of it
(none exist by design — see the README's Controls section).

### Q: switching to the full desktop and back

`Q` needs `lightdm` (installed by the full Desktop image, §1) to still be
present but disabled at boot (`systemctl is-enabled lightdm` should say
`disabled` — the kiosk owns `tty1` at boot instead). The mechanism is
`launcher.service`'s `Conflicts=lightdm.service`: starting either service
auto-stops the other, so switching sessions is just one `systemctl start`
each way — no manual "stop the other one first" step, and no risk of both
fighting over the same VT at once.

**Only install the "Emulator Launcher" desktop icon/menu entry below on a
Pi 3B, and only if you actually want the round trip back into the kiosk
from the desktop.** On a Pi 4 + the project's 1024x768 HDMI panel, that
specific transition (tearing down the desktop's live Xorg session and
starting the kiosk's back-to-back) reliably triggers a kernel `WARNING`
in `drivers/gpu/drm/vc4/vc4_hvs.c` (`__vc4_hvs_stop_channel`) that leaves
the display flickering blue/black - confirmed via a direct `dmesg`
reproduction, and unfixed by both a delay-based workaround and
`max_framebuffers=1`; no kernel update addressing it was available as of
2026-09-22. The same transition was directly confirmed clean (zero new
kernel log lines) on a Pi 3B. `Q` (kiosk → desktop) itself isn't affected
either way and is safe to set up on any Pi - just skip the icon below on
a Pi 4 and use a plain `sudo reboot` from the desktop to get back to the
kiosk instead. (Also worth knowing before bothering with this on a
Pi 3B at all: LisaEm's performance there is poor enough - see the
project's CLAUDE.md hardware notes - that a Pi 3B usually isn't the
recommended target regardless.)

Install the "Emulator Launcher" desktop entry - as both a desktop icon and an
Applications-menu entry, since rpd-labwc's desktop-icon rendering has
been inconsistent:

```
chmod +x ~/lisa-mini-pi/software/lisa-pi-launcher/system/back-to-kiosk.sh
mkdir -p ~/Desktop ~/.local/share/applications
cp ~/lisa-mini-pi/software/lisa-pi-launcher/system/back-to-kiosk.desktop ~/Desktop/back-to-kiosk.desktop
chmod +x ~/Desktop/back-to-kiosk.desktop
cp ~/lisa-mini-pi/software/lisa-pi-launcher/system/back-to-kiosk.desktop ~/.local/share/applications/back-to-kiosk.desktop
chmod +x ~/.local/share/applications/back-to-kiosk.desktop
```

The desktop icon needs one more step, or double-clicking it prompts
"this text file appears to be an executable..." instead of launching -
PCManFM only trusts `.desktop` files created through its own UI by
default, not ones just copied in:

```
gio set ~/Desktop/back-to-kiosk.desktop "metadata::trusted" true
```

This is a per-file extended attribute, not something that survives a
fresh `cp` - re-run it if the desktop icon is ever replaced. (`back-to-
kiosk.sh` and `back-to-kiosk.desktop` ship in `system/` and get deployed
with everything else via the repo's normal rsync/copy; the commands
above are only needed the first time, to actually place/trust the icon
outside the repo's own tree.)

**Confirmed working on real hardware** (2026-09-21, Pi 3B): pressing `Q`
at the picker switches cleanly to the full desktop, and the "Emulator
Launcher" icon switches back - on a Pi 3B specifically, see the warning
above for why a Pi 4 shouldn't have the icon installed at all
(2026-09-22). If a future Pi's `lightdm` doesn't claim the VT cleanly
once `launcher.service` releases it, check `journalctl -u lightdm.service`
for what went wrong.

## 8. Verifying the round trip

For each system in `config.json`: launch it from the picker, confirm
keyboard input works both inside the emulator and back at the picker
afterward, and confirm a guest shutdown (not a force-kill) returns
cleanly to the picker. This project's history has several examples of
"launches fine" not implying "the full round trip works" — X11
focus-handoff and process-exit-on-shutdown bugs have each independently
broken this in the past.

## Known gaps (update this section as they close)

- ~~**§3's LisaEm build instructions are for the wrong fork/branch on at
  least one real Pi.**~~ **CLOSED (2026-09-26).** §3 now clones
  `--branch lisa-fixes-1024x768` into `~/lisaem-fixes-src`, matching what
  `lisa-run-with-led.sh` actually hardcodes as `LISAEM_BIN`
  (`$HOME/lisaem-fixes-src/bin/lisaem`) and what `docs/software-setup.md`
  and `provision.sh` already used — the old `~/lisaem`/no-branch clone
  would have built a binary the launcher could never find. This section
  previously also flagged a missing `-M`/`-M-` flag on this branch for
  keeping Shut Down mouse-reachable — `docs/software-setup.md` §2 already
  documents that this was fixed by patching the branch's `-k` flag to
  leave the mouse-to-top-menu setting at its saved default instead of
  forcing it off, so no CLI flag is needed; not re-verified independently
  in this pass.
- LisaEm's/Basilisk II's asset-provisioning steps (§3-4) don't yet
  record exactly how `boot.ROM`/`lisaem-widget.dc42`/`mac-lciii.rom`/
  `macos753.image` were originally obtained/created for this specific
  build — fill this in next time it's done from scratch.
- The wxWidgets 3.2.1 source-build commands (§3) aren't captured yet.
- NEXT and APPLE II are now implemented (Previous and LinApple
  respectively) but only documented in `../../docs/software-setup.md`
  §6-7 - this file was never updated to cover them, see the note at the
  top.
- **Pi 3B does not get Previous or LinApple** (2026-09-25 decision) - the
  Pi 3B doesn't have the power/performance headroom for them on top of
  LisaEm/Basilisk II/Mini vMac. `config.json` is shared across both Pis
  (all paths are now uniform, no per-machine divergence needed for the
  five-system config), but the Pi 3B simply never got the two `.deb`s
  installed - `check_deps.py` correctly flags `next`/`apple2` as missing
  there, which is expected, not a bug. The Pi 3B was also powered off
  without its physical GPIO power button/LED ever being wired up, so the
  button/LED extensions for Previous/LinApple (`docs/software-setup.md`
  §2) were never tested on it either.
- Mini vMac was also added to a second Pi (`config.json` from the first Pi
  won't just work there unless the same binaries/ROMs/disks are placed at
  the same paths) — this file assumes one Pi at a time; note which
  physical unit each of your own local notes refers to.
- This file and `../../docs/software-setup.md` overlap and haven't been
  reconciled into one - see the note at the top of this file.
- **The desktop→kiosk switch (the "Emulator Launcher" icon) is unfixed on
  Pi 4 and the icon should not be installed there - see the warning in
  §7 above.** On real hardware (Pi 4 + the project's 1024x768 HDMI
  panel), tearing down the desktop's Xorg session and starting the
  kiosk's back-to-back reliably triggers a kernel `WARNING` in
  `drivers/gpu/drm/vc4/vc4_hvs.c` (`__vc4_hvs_stop_channel`, hit via the
  outgoing Xorg's `FBIOBLANK` ioctl on exit), which leaves the display
  flickering blue/black until the new X session gives up and
  crash-loops. Confirmed directly reproducible via `dmesg` on Pi 4 and
  directly confirmed NOT reproducible the same way on Pi 3B - this is
  specific to the Pi 4 hardware/kernel combination, not the launcher
  code. Two mitigations were tried and both failed to fix it: a
  stop-then-sleep-then-start delay in `system/back-to-kiosk.sh` (kept -
  harmless, but doesn't help), and `max_framebuffers=1` in config.txt (to
  rule out Pi 4's always-enumerated-but-disconnected second HDMI output's
  HVS channel as the cause - it wasn't). No kernel update fixing this was
  available as of 2026-09-22. `Q` (kiosk → desktop) itself is unaffected
  and still works fine on any Pi; a plain reboot is the way back into the
  kiosk on a Pi 4 instead of the icon.

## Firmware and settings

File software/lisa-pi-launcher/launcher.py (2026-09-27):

"""Entry point: fullscreen pygame kiosk showing a keyboard/mouse-driven
"CHOOSE YOUR ADVENTURE" system picker, launching the selected emulator as
a subprocess and returning to the picker when it exits."""

import os
import subprocess
import sys
import time

# Must be set before pygame.init() creates the display. SDL auto-minimizes
# an exclusive-fullscreen window when it loses input focus by default. That
# hint was never observed under the old no-window-manager kiosk session
# (focus loss was never reliably detected there), but now that openbox
# correctly hands focus to a newly-launched emulator's window, this
# launcher's own window legitimately loses focus - and without this,
# SDL would iconify/unmap it, leaving nothing on screen to return to once
# the emulator exits.
os.environ.setdefault("SDL_VIDEO_MINIMIZE_ON_FOCUS_LOSS", "0")

# SDL2 auto-captures the mouse on a button press by default (so a
# click-drag that leaves the window still tracks correctly), releasing
# that capture only once SDL itself processes the matching button-release
# event. Selecting a system with a mouse click goes straight from that
# MOUSEBUTTONDOWN into a blocking subprocess.run() for the whole emulator
# session - SDL never gets to pump the button-release, so its capture
# grab was suspected of outliving the click and silently swallowing all
# pointer events meant for the emulator's window (window-manager focus
# and an X pointer grab are independent - LisaEm correctly had real focus
# the whole time per an xdotool diagnostic, yet still never received a
# single mouse event). Disabling auto-capture removes that grab from the
# picture entirely rather than trying to race its release.
os.environ.setdefault("SDL_MOUSE_AUTO_CAPTURE", "0")

import pygame

_DIAG_EVENT_NAMES = {
    pygame.ACTIVEEVENT: "ACTIVEEVENT",
    pygame.WINDOWFOCUSGAINED: "WINDOWFOCUSGAINED",
    pygame.WINDOWFOCUSLOST: "WINDOWFOCUSLOST",
    pygame.WINDOWTAKEFOCUS: "WINDOWTAKEFOCUS",
    pygame.WINDOWSHOWN: "WINDOWSHOWN",
    pygame.KEYDOWN: "KEYDOWN",
}


_DIAG_LOG_PATH = "/home/wottle/lisa-pi-launcher/focus_diag.log"


def _diag_log(msg: str) -> None:
    line = f"[FOCUS-DIAG {time.time():.3f}] {msg}"
    print(line, flush=True)
    try:
        with open(_DIAG_LOG_PATH, "a") as f:
            f.write(line + "\n")
    except OSError:
        pass

import cursor
import theme
import x11focus
from bitmap_font import CHAR_WIDTH  # noqa: F401 (documents the font dependency)
from config import load_config
from rendering import (
    ItemVisual,
    confirmation_hit_test,
    draw_checkerboard_cached,
    draw_confirmation_dialog,
    footer_hit_test,
    hit_test,
    render_frame,
)
from state import LauncherState, Phase

# The Lisa-style boot-diagnostic animation (CPU/MEM/I/O/EXPANSION test,
# see boot_diag.py) is disabled as of the 2026-09-25 "CHOOSE YOUR
# ADVENTURE" redesign - the picker now shows immediately on launch, no
# animated pre-phase. boot_diag.py itself is left in place (and its own
# tests still pass) in case it's ever wanted back; this file simply
# doesn't import or call it anymore.


def _load_icon(path: str) -> pygame.Surface:
    return pygame.image.load(path).convert()


def _system_items_visual(state: LauncherState, icons: dict[str, pygame.Surface]) -> list[ItemVisual]:
    items = []
    for index, system in enumerate(state.systems):
        items.append(ItemVisual(
            icon=icons[system.id],
            label=system.name,
            status_icon=None,
            selected=(index == state.selected_index),
            subtitle=system.subtitle,
        ))
    return items


def _draw_frame(
    real_screen: pygame.Surface,
    header_text: str,
    items: list[ItemVisual],
    hovered_footer: str | None = None,
) -> None:
    # The checkerboard is drawn directly onto real_screen at its own
    # native resolution (never scaled, so it never aliases/moires);
    # render_frame then draws the opaque panel directly on top of it, on
    # this same surface - see theme.py for why there's no separate
    # logical surface scaled up to this one anymore.
    draw_checkerboard_cached(real_screen, theme.CHECKER_CELL_SIZE)
    render_frame(real_screen, header_text, items, hovered_footer=hovered_footer)
    pygame.display.flip()


def _draw_confirmation(
    real_screen: pygame.Surface,
    header_text: str,
    items: list[ItemVisual],
    action: str,
    hovered: str | None,
) -> None:
    # The picker stays visible underneath the dialog (matches how a modal
    # dialog normally sits over its parent window) rather than blanking
    # the screen.
    draw_checkerboard_cached(real_screen, theme.CHECKER_CELL_SIZE)
    render_frame(real_screen, header_text, items)
    draw_confirmation_dialog(real_screen, action, hovered=hovered)
    pygame.display.flip()


def _open_fullscreen() -> pygame.Surface:
    # (0, 0) tells SDL to use the current desktop resolution for fullscreen,
    # so the launcher fills whatever display it's actually running on
    # instead of a fixed 1024x768 that may not match the real panel. The
    # picker's own content is still laid out for a fixed 1024x768 (see
    # theme.py) - on a differently-sized display it draws at that fixed
    # size/position rather than adapting, which is an accepted tradeoff.
    return pygame.display.set_mode((0, 0), pygame.FULLSCREEN)


def main() -> None:
    pygame.init()
    pygame.mouse.set_visible(True)
    cursor.set_cursor()
    # With no window manager to broker input focus, X11's default focus
    # revert-to behavior after the emulator's window closes doesn't
    # reliably bring keyboard focus back to this window (mouse events
    # still worked, since those aren't focus-gated) - grabbing input
    # explicitly forces it back here regardless of what X would have done
    # on its own.
    pygame.event.set_grab(True)

    real_screen = _open_fullscreen()
    clock = pygame.time.Clock()

    systems = load_config("config.json")

    icons: dict[str, pygame.Surface] = {}
    for system in systems:
        icons[system.id] = _load_icon(system.icon)

    state = LauncherState(systems)

    def _perform_confirmed_action(action: str) -> bool:
        """Runs whatever S/Q used to do immediately - now only reached
        after the user has confirmed the dialog. Returns False if the
        main loop should stop running (the Q/quit-to-desktop case)."""
        if action == "shutdown":
            subprocess.run(["systemctl", "poweroff"])
            return True
        # action == "quit": suppress the watchdog first - it doesn't know
        # about the desktop session and would otherwise see no
        # launcher/emulator process running and restart the kiosk out
        # from under it within 30s. Starting lightdm.service is what
        # actually switches sessions (see launcher.service's
        # Conflicts=lightdm.service - starting it auto-stops us, which is
        # why this is the last action taken here).
        subprocess.run(["systemctl", "stop", "launcher-watchdog.timer"])
        subprocess.run(["systemctl", "start", "lightdm.service"])
        return False

    running = True
    hovered_footer: str | None = None
    hovered_confirm: str | None = None
    while running:
        clock.tick(30)

        for event in pygame.event.get():
            if event.type in _DIAG_EVENT_NAMES:
                grab_state = pygame.event.get_grab()
                active_state = pygame.display.get_active()
                _diag_log(f"{_DIAG_EVENT_NAMES[event.type]} grab={grab_state} active={active_state} raw={event}")

            if event.type == pygame.QUIT:
                running = False
            elif state.phase == Phase.CONFIRMING:
                # SHUT DOWN/QUIT are destructive/disruptive enough to need
                # an explicit confirmation step - see the
                # 2026-09-27 clickable-footer decision. While confirming,
                # only RETURN/ESCAPE and the dialog's own CONFIRM/CANCEL
                # buttons do anything; arrow keys, item clicks, etc. are
                # ignored so a stray keypress can't launch a system or
                # move the selection underneath the dialog.
                if event.type == pygame.KEYDOWN:
                    if event.key == pygame.K_RETURN:
                        action = state.confirm_pending()
                        hovered_confirm = None
                        if not _perform_confirmed_action(action):
                            running = False
                    elif event.key == pygame.K_ESCAPE:
                        state.cancel_pending()
                        hovered_confirm = None
                elif event.type == pygame.MOUSEMOTION:
                    hovered_confirm = confirmation_hit_test(event.pos)
                elif event.type == pygame.MOUSEBUTTONDOWN and event.button == 1:
                    choice = confirmation_hit_test(event.pos)
                    if choice == "confirm":
                        action = state.confirm_pending()
                        hovered_confirm = None
                        if not _perform_confirmed_action(action):
                            running = False
                    elif choice == "cancel":
                        state.cancel_pending()
                        hovered_confirm = None
            elif event.type == pygame.KEYDOWN:
                if event.key == pygame.K_LEFT:
                    state.move_selection(-1)
                elif event.key == pygame.K_RIGHT:
                    state.move_selection(1)
                elif event.key == pygame.K_RETURN:
                    real_screen = _launch_selected(state, real_screen, icons)
                elif event.key == pygame.K_s:
                    state.request_confirmation("shutdown")
                    hovered_footer = None
                elif event.key == pygame.K_r:
                    # Not shown in the footer hint (only S/Q are), and
                    # deliberately left out of the confirmation-dialog
                    # treatment added for S/Q - see the 2026-09-27
                    # decision to leave R exactly as it was.
                    subprocess.run(["systemctl", "reboot"])
                elif event.key == pygame.K_q:
                    state.request_confirmation("quit")
                    hovered_footer = None
            elif event.type == pygame.MOUSEMOTION:
                # Hover selects, mirroring the arrow keys - so someone
                # without a keyboard can see what they're about to pick
                # before committing with a click. event.pos is already in
                # screen coordinates, matching item_layout()/hit_test()
                # directly now that there's no separate logical surface.
                index = hit_test(_system_items_visual(state, icons), event.pos)
                if index is not None:
                    state.select_index(index)
                hovered_footer = footer_hit_test(_system_items_visual(state, icons), event.pos)
            elif event.type == pygame.MOUSEBUTTONDOWN and event.button == 1:
                footer_choice = footer_hit_test(_system_items_visual(state, icons), event.pos)
                if footer_choice is not None:
                    state.request_confirmation(footer_choice)
                    hovered_footer = None
                else:
                    index = hit_test(_system_items_visual(state, icons), event.pos)
                    if index is not None:
                        state.select_index(index)
                        real_screen = _launch_selected(state, real_screen, icons)

        items = _system_items_visual(state, icons)
        if state.phase == Phase.CONFIRMING:
            _draw_confirmation(real_screen, state.header_text(), items, state.pending_action, hovered_confirm)
        else:
            _draw_frame(real_screen, state.header_text(), items, hovered_footer)

    pygame.quit()


def _launch_selected(
    state: LauncherState,
    real_screen: pygame.Surface,
    icons: dict[str, pygame.Surface],
) -> pygame.Surface:
    state.start_selected()

    # Render and flip one STARTING-phase frame first, so the
    # "STARTING <NAME>..." header text is actually visible for a moment
    # rather than being set and discarded before the next flip.
    items = _system_items_visual(state, icons)
    _draw_frame(real_screen, state.header_text(), items)

    # Cover the screen in solid black and leave this window mapped, rather
    # than tearing the display down and recreating it. There's no window
    # manager in this kiosk session to iconify/hide us any other way, and
    # destroying and recreating the display briefly exposes the bare X11
    # root window (the desktop background) in the gap. Left mapped and
    # black, this window just sits behind whatever the emulator maps on
    # top of it - X11 stacks a newly-mapped window above existing ones by
    # default with no window manager involved - and reappears exactly as
    # it was the instant the emulator's window is gone.
    real_screen.fill((0, 0, 0))
    pygame.display.flip()

    # Release input grab so the emulator's own window can actually receive
    # keyboard/mouse input - holding it while a second window is meant to
    # be focused would fight the emulator for input.
    pygame.event.set_grab(False)
    # pygame.event.set_grab(False) alone releases SDL's own bookkeeping
    # but was observed to leave the actual X11 pointer grab in place when
    # launching via a mouse click (not Enter) - see x11focus.py's
    # release_pointer_grab() docstring for the symptom this fixes.
    x11focus.release_pointer_grab()
    # The actual fix for LisaEm's mouse freezing when launched by click:
    # let the emulator's about-to-map window pick up real X input focus
    # itself instead of leaving it pinned on this (now backgrounded)
    # window - see release_focus_to_pointer_root()'s docstring.
    x11focus.release_focus_to_pointer_root()
    # Basilisk II and Mini vMac both take over the cursor themselves once
    # running, so the launcher's big custom pointer naturally disappears;
    # LisaEm never touches cursor state at all, so without this it just
    # keeps showing our last-defined cursor image on top of LisaEm's own
    # screen for the whole session. Hide it explicitly instead of
    # depending on each emulator's own behavior.
    pygame.mouse.set_visible(False)
    _diag_log(f"pre-launch grab={pygame.event.get_grab()} active={pygame.display.get_active()}")

    launch_failed = False
    try:
        # start_new_session detaches the emulator into its own process
        # group. Without it, the emulator shares this process's group by
        # default, and at least one emulator (Basilisk II) sends a signal
        # to its whole process group as part of its shutdown sequence -
        # which was killing this launcher process too, silently, with no
        # traceback, the instant the guest OS finished shutting down.
        subprocess.run(state.selected.command, start_new_session=True)
    except OSError:
        # Missing binary, permission denied, etc. Don't let a bad
        # `command` entry crash the whole kiosk process - under
        # Restart=always that would just silently respawn back to the
        # picker with no indication of what went wrong.
        launch_failed = True
    finally:
        state.finish_starting()
        _diag_log(f"post-subprocess.run() returned, launch_failed={launch_failed} "
                  f"grab-before-reclaim={pygame.event.get_grab()} active={pygame.display.get_active()}")
        # Reclaim input focus now that the emulator's window is gone (see
        # the comment in main() - X11 doesn't reliably hand it back on
        # its own with no window manager in this session).
        pygame.mouse.set_visible(True)
        pygame.event.set_grab(True)
        x11focus.reclaim_focus(real_screen)
        _diag_log(f"grab-after-reclaim={pygame.event.get_grab()} active={pygame.display.get_active()}")
        # Drain keystrokes queued while the emulator subprocess was
        # running, so e.g. a leftover Enter doesn't immediately relaunch
        # it once the picker's event loop resumes.
        pygame.event.clear()

    if launch_failed:
        _draw_frame(real_screen, "LAUNCH FAILED", _system_items_visual(state, icons))
        pygame.time.wait(1000)

    return real_screen


if __name__ == "__main__":
    sys.exit(main() or 0)

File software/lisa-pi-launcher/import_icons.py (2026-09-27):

"""One-time tool: converts the provided high-resolution source icons into
crisp PNGs under icons/ (theme.ICON_SIZE for system and boot-diagnostic
icons, theme.CHECK_ICON_SIZE for the smaller "completed" check badge),
replacing the procedurally-drawn placeholders gen_icons.py made for these
same names. Not part of the runtime path - run directly
(`python3 import_icons.py <source_dir>`) whenever new source art needs
importing.

Two conversion modes (see convert_icon's `threshold` parameter):
- Hard black/white threshold (diag icons, check.png): for source art
  that's already pure black/white line art (no antialiasing/gradients).
  A high-quality downscale followed by a hard threshold keeps that
  purity - avoiding the gray edge pixels a naive resize would leave -
  while cleanly reducing to our target size.
- Smooth grayscale, no threshold (the main system icons as of the
  2026-09-27 icon refresh): for source art with real tonal detail (e.g.
  the classic Mac Finder face's two-tone shading) that a hard threshold
  would destroy - confirmed by a direct side-by-side comparison, not
  guessed. Still monochrome (color source art is composited/grayscaled
  same as before), just not reduced all the way to 1-bit.
"""

import sys

from PIL import Image, ImageOps

import theme

_SOURCE_TO_ICON = {
    "lisa.png": "lisa.png",
    "macos7.png": "macintosh.png",
    "macos6.jpg": "macintosh6.png",
    "next.png": "next.png",
    "appleii.png": "apple2.png",
}

# Boot-diagnostic source art, sized to theme.ICON_SIZE like the icons
# above. check.png is the smaller "completed" status badge and is sized
# separately - see _SOURCE_TO_CHECK_ICON below.
_SOURCE_TO_DIAG_ICON = {
    "CPU.png": "diag_cpu.png",
    "MEM.png": "diag_mem.png",
    "io.png": "diag_io.png",
    "expansion_cards.png": "diag_expansion.png",
}

_CHECK_SOURCE = "check.png"
_CHECK_ICON = "check.png"

_THRESHOLD = 128


def convert_icon(source_path: str, size: int, threshold: bool = True) -> Image.Image:
    image = Image.open(source_path)
    if image.mode in ("RGBA", "LA") or "transparency" in image.info:
        # Composite onto white first: this source's transparent pixels
        # are stored as black (0,0,0,0), which a direct convert("L")
        # would read as black background instead of white, since L
        # conversion drops the alpha channel and just keeps the (wrong)
        # RGB value underneath.
        background = Image.new("RGBA", image.size, (255, 255, 255, 255))
        image = Image.alpha_composite(background.convert("RGBA"), image.convert("RGBA"))
    image = image.convert("L")
    # Crop to the actual ink's bounding box (plus a little padding) before
    # resizing: the source art isn't drawn at a consistent size relative
    # to its canvas (one icon's content filled ~50% of its canvas width,
    # another's only ~19%), so resizing the full canvas for every icon
    # left some noticeably smaller/thinner than others - thin enough,
    # for the smallest ones, that a stroke could vanish entirely under
    # the hard threshold below.
    # getbbox() treats any non-pure-white pixel as content, but these
    # source images have faint background noise across the whole canvas
    # (not flat 255) - without a stricter threshold here first, the
    # detected bbox is the entire canvas. This threshold is only used to
    # find the crop region; the actual resize below still uses the
    # original (unthresholded) pixel values for a clean LANCZOS downscale.
    bbox_mask = image.point(lambda p: 0 if p < 200 else 255)
    content_bbox = ImageOps.invert(bbox_mask).getbbox()
    if content_bbox is not None:
        left, top, right, bottom = content_bbox
        # A square crop centered on the content, sized to its larger
        # dimension plus padding - not just its own (left, top, right,
        # bottom) box - so content narrower than it is tall (or vice
        # versa) keeps its original aspect ratio instead of being
        # stretched to fill a square target size.
        content_size = max(right - left, bottom - top)
        half_side = content_size // 2 + content_size // 10
        center_x, center_y = (left + right) // 2, (top + bottom) // 2
        image = image.crop((
            max(0, center_x - half_side),
            max(0, center_y - half_side),
            min(image.width, center_x + half_side),
            min(image.height, center_y + half_side),
        ))
    if threshold:
        # NEAREST, not LANCZOS: this source art is already blocky pixel
        # art, not a smooth/photographic image, so a smoothing resample
        # algorithm is the wrong tool - it blends soft gray edges that
        # the hard threshold below then chops at a somewhat arbitrary
        # boundary, producing slightly inconsistent/jagged edges
        # compared to NEAREST (confirmed side by side at both 32px and
        # 48px target sizes).
        image = image.resize((size, size), Image.NEAREST)
        # Hard-threshold back to pure black/white: even NEAREST can land
        # exactly between two source shades at some pixels.
        image = image.point(lambda p: 255 if p >= _THRESHOLD else 0)
        return image.convert("1")
    # LANCZOS here, not NEAREST: this path is for source art with real
    # tonal gradients we want to keep (see the module docstring) - a
    # smoothing resample is the right tool for that, unlike for the
    # blocky pixel-art path above.
    return image.resize((size, size), Image.LANCZOS)
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

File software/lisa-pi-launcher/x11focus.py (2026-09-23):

"""Explicit X11 input-focus/pointer-grab handling, via ctypes bindings to
libX11.

reclaim_focus() exists because pygame.event.set_grab() alone was not
enough to bring keyboard input back after returning from BasiliskII: with
no window manager in this kiosk session, X's own focus-revert behavior
sometimes leaves input focus on no window at all (RevertToNone) once the
emulator's window is destroyed, and SDL's grab does not override that -
so no KEYDOWN events reach this process at all until focus is explicitly
reassigned back to our own window.

release_pointer_grab() targets a related but distinct symptom: it turned
out not to be the actual fix for LisaEm's frozen mouse (see
release_focus_to_pointer_root() below), but is harmless to keep - an
explicit XUngrabPointer still closes a real gap between SDL's grab
bookkeeping and the X server's actual grab state before a new window
maps.

release_focus_to_pointer_root() is what actually explains "LisaEm's
mouse only breaks when launched by clicking, not by pressing Enter":
this kiosk has no window manager riding herd on focus for anything it
didn't itself initiate, and after a mouse click, real input focus can
stay pinned on this (now black, backgrounded) launcher window instead of
transferring to the emulator's newly-mapped one - X pointer motion
routing is stacking-based and mostly focus-independent, but wxWidgets
(LisaEm's toolkit) was observed to just not process mouse-move handling
for a top-level window that the X server doesn't consider focused.
Enter never has this problem because there's no click for anything to
mis-attribute focus around in the first place. Setting focus to
PointerRoot - a special X input-focus mode meaning "whatever window the
pointer physically ends up over, dynamically, needs no window ID known
in advance" - lets the soon-to-map emulator window pick up real focus
itself the moment it appears, the same way it would if no other window
had opinions about focus at all.
"""

import ctypes

import pygame

_REVERT_TO_PARENT = 2
_REVERT_TO_POINTER_ROOT = 1
_POINTER_ROOT = 1
_CURRENT_TIME = 0


def _open_display():
    try:
        libx11 = ctypes.CDLL("libX11.so.6")
    except OSError:
        return None, None
    libx11.XOpenDisplay.restype = ctypes.c_void_p
    display = libx11.XOpenDisplay(None)
    if not display:
        return None, None
    return libx11, display


def release_pointer_grab() -> None:
    libx11, display = _open_display()
    if libx11 is None:
        return
    try:
        libx11.XUngrabPointer(ctypes.c_void_p(display), ctypes.c_ulong(_CURRENT_TIME))
        libx11.XFlush(ctypes.c_void_p(display))
    finally:
        libx11.XCloseDisplay(ctypes.c_void_p(display))


def release_focus_to_pointer_root() -> None:
    libx11, display = _open_display()
    if libx11 is None:
        return
    try:
        libx11.XSetInputFocus(
            ctypes.c_void_p(display),
            ctypes.c_ulong(_POINTER_ROOT),
            ctypes.c_int(_REVERT_TO_POINTER_ROOT),
            ctypes.c_ulong(_CURRENT_TIME),
        )
        libx11.XFlush(ctypes.c_void_p(display))
    finally:
        libx11.XCloseDisplay(ctypes.c_void_p(display))


def reclaim_focus(real_screen: pygame.Surface) -> None:
    wm_info = pygame.display.get_wm_info()
    window_id = wm_info.get("window")
    if not window_id:
        return

    libx11, display = _open_display()
    if libx11 is None:
        return

    try:
        libx11.XSetInputFocus(
            ctypes.c_void_p(display),
            ctypes.c_ulong(window_id),
            ctypes.c_int(_REVERT_TO_PARENT),
            ctypes.c_ulong(_CURRENT_TIME),
        )
        libx11.XFlush(ctypes.c_void_p(display))
    finally:
        libx11.XCloseDisplay(ctypes.c_void_p(display))

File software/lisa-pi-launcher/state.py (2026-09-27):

"""The selection state machine: which system is highlighted, and whether
we're idly selecting or currently launching one."""

from enum import Enum, auto

from config import SystemEntry


class Phase(Enum):
    SELECTING = auto()
    STARTING = auto()
    CONFIRMING = auto()


class LauncherState:
    def __init__(self, systems: list[SystemEntry]):
        if not systems:
            raise ValueError("LauncherState requires at least one system")
        self._systems = systems
        self._selected_index = 0
        self._phase = Phase.SELECTING
        self._pending_action: str | None = None

    def move_selection(self, delta: int) -> None:
        self.select_index(self._selected_index + delta)

    def select_index(self, index: int) -> None:
        """Sets the selection directly (clamped) - used by mouse hover/
        click selection, where the target index comes from a hit test
        rather than a relative +1/-1 move."""
        self._selected_index = max(0, min(len(self._systems) - 1, index))

    @property
    def selected_index(self) -> int:
        return self._selected_index

    @property
    def selected(self) -> SystemEntry:
        return self._systems[self._selected_index]

    @property
    def phase(self) -> Phase:
        return self._phase

    @property
    def systems(self) -> list[SystemEntry]:
        return list(self._systems)

    def start_selected(self) -> None:
        self._phase = Phase.STARTING

    def finish_starting(self) -> None:
        self._phase = Phase.SELECTING

    @property
    def pending_action(self) -> str | None:
        return self._pending_action

    def request_confirmation(self, action: str) -> None:
        """Enters the CONFIRMING phase for a destructive/disruptive action
        (e.g. "shutdown", "quit") that shouldn't happen on a single
        keypress or click - see confirm_pending()/cancel_pending()."""
        self._pending_action = action
        self._phase = Phase.CONFIRMING

    def confirm_pending(self) -> str:
        """Returns the pending action so the caller can perform it, and
        returns to SELECTING. Raises if there's nothing pending - callers
        should only reach this from CONFIRMING."""
        if self._pending_action is None:
            raise ValueError("confirm_pending() called with no pending action")
        action = self._pending_action
        self._pending_action = None
        self._phase = Phase.SELECTING
        return action

    def cancel_pending(self) -> None:
        self._pending_action = None
        self._phase = Phase.SELECTING

    def header_text(self) -> str:
        if self._phase == Phase.STARTING:
            return f"STARTING {self.selected.name}..."
        return "CHOOSE YOUR ADVENTURE"

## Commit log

2026-09-21 Initial commit: Lisa Mini Pi umbrella project
    Pulls together the kiosk launcher (previously untracked on the Pi at
    ~/lisa-pi-launcher), the GPIO power-button/LED scripts written alongside
    it, and a software setup guide covering the patched LisaEm build, GPIO
    wiring, and boot-time systemd configuration. Placeholder directories for
    3D models and assembly instructions, to be filled in later.
2026-09-21 Higher-res launcher icons, Q-key desktop escape hatch, reconcile with power-button fixes
    Icons (lisa/macintosh/apple2/next) replaced with higher-res versions.
    New Q-key flow (launcher.py + system/back-to-kiosk.sh + .desktop file):
    lets you drop from the kiosk to the full Raspberry Pi desktop and back,
    via launcher.service <-> lightdm.service both Conflicts=-ing each other
    (so starting either auto-stops the other) plus a scoped polkit rule
    allowing wottle to start/stop just those three units without auth.
    Restored this session's config.json and xsession-launcher.sh changes
    (the lisa entry launching lisa-run-with-led.sh, and the persistent
    GPIO power-button watcher startup line), which the s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
    [launcher.py]
2026-09-21 Sync latest launcher work into the umbrella repo, wire in LED/GPIO scripts
    software/lisa-pi-launcher was stale relative to the separate lisa-pi-
    launcher checkout this was originally copied from - missing the pixel-
    doubling removal, icon rework, "Q switches to desktop" feature, and
    more. Synced the latest version in, keeping lisa-run-with-led.sh and
    lisa-power-button-watcher.sh (which only exist here).
    Wired them into the boot path:
    - config.json's lisa entry now launches through lisa-run-with-led.sh
    instead of the raw LisaEm binary, so the GPIO LED actually lights up
    when LisaEm runs via the launcher menu, not just via the physical
    button.
    - xsession-launcher.sh now starts lisa-powe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
    [cursor.py, import_icons.py, launcher.py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]
2026-09-22 Add distinct Mac OS 6/7 entries, fix picker sluggishness from per-frame icon inversion
    - config.json: split the single MACINTOSH entry into MAC OS 6 (System
    6.0.8, Mini vMac) and MAC OS 7 (System 7.5.3, Basilisk II), each with
    its own icon, and reordered so 6.0.8 comes before 7.5.3.
    - import_icons.py: wire macos6.png source art to icons/macintosh6.png.
    - rendering.py: cache each icon's selected-state inverted copy instead
    of recomputing it with a pure-Python per-pixel get_at/set_at loop on
    every frame. That loop scaled with ICON_SIZE^2 and became a real
    bottleneck once icons grew from 48px to 128px (16384 pixels/frame in
    interpreted Python). Now a one-time BLEND_RGB_SUB blit per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
    [import_icons.py, rendering.py]
2026-09-22 Add custom Lisa Mini boot splash and install script
    Replaces the stock Raspberry Pi OS Plymouth "pix" theme image with a
    project-specific one. install.sh backs up the stock splash.png once,
    copies the custom image into place, and rebuilds the initramfs (required
    on current Raspberry Pi OS, since Plymouth reads its theme out of the
    initramfs at early boot rather than the live rootfs).
2026-09-22 Document disabling the firmware rainbow splash screen
    disable_splash=1 in config.txt skips the GPU firmware's rainbow
    diagnostic test pattern, falling through to the custom Plymouth splash
    almost immediately instead. No file-based replacement is possible at
    that pre-kernel stage - it's rendered by firmware, not read from disk.
2026-09-22 Add delay-based workaround for vc4 kernel bug on desktop->kiosk switch
    Explicitly stop lightdm.service and sleep 2s before starting
    launcher.service, instead of relying on Conflicts= to do both in one
    systemd transaction. The back-to-back CRTC teardown/setup was reliably
    triggering a kernel WARNING in vc4_hvs.c (__vc4_hvs_stop_channel) on
    real hardware (Pi 4 + the 1024x768 HDMI panel), leaving the display
    flickering blue/black. This is a mitigation for a kernel/GPU driver bug,
    not a real fix - no kernel update addressing it was available yet.
2026-09-23 Explicitly release the X11 pointer grab before launching an emulator
    pygame.event.set_grab(False) releases SDL's own grab bookkeeping but was
    observed to leave the actual X server pointer grab in place when
    launching LisaEm via a mouse click rather than Enter - the launcher's
    cursor stayed on screen and LisaEm's own emulated pointer never received
    motion events, frozen at its origin. Adds x11focus.release_pointer_grab()
    (an explicit XUngrabPointer, mirroring the existing reclaim_focus()
    pattern already used for the analogous keyboard-focus issue) and calls
    it right before subprocess.run in _launch_selected.
    [launcher.py, x11focus.py]
2026-09-23 Add a startup dependency check, logged every kiosk boot
    check_deps.py verifies required/optional PATH commands, every
    filesystem-path-looking argument in config.json's system commands
    (catching missing ROM/disk/binary paths generically, since those differ
    per Pi), the installed systemd units, and the polkit rule - then logs
    timestamped pass/fail/warn results to
    ~/lisa-mini-pi-dependency-check.log. Deliberately stdlib-only (no
    pygame/PIL import) and always exits 0: a missing optional asset
    shouldn't block the kiosk from booting into whatever does work, but it
    should be loud in the log instead of surfacing later as a confusing
    runtime failure - this would have caught Pi4's missing xdotool
    imme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
    [check_deps.py]
2026-09-23 Fix false FAIL on permission-denied paths in check_deps.py
    os.path.exists() silently swallows PermissionError and reports False,
    which was a false FAIL for /etc/polkit-1/rules.d/10-lisa-launcher-power.rules
    - that directory isn't world-readable, so a normal user genuinely can't
    tell "missing" from "can't check" there. Call os.stat() directly and
    report a WARN instead. Caught by testing check_deps.py live on Pi4.
    [check_deps.py]
2026-09-23 Fix LisaEm's mouse freezing on mouse-click launch: focus-stealing prevention
    Keyboard-launch (Enter) always worked; only launching via a mouse click
    left LisaEm's window never receiving mouse motion, with the launcher's
    own cursor stuck on screen. Root cause: this kiosk has no window manager
    brokering focus for windows it didn't itself initiate, so after a click,
    real X input focus can stay pinned on the launcher's own (now
    backgrounded) window instead of transferring to the emulator's
    newly-mapped one - wxWidgets appears to just not process mouse-move
    handling for a top-level window the X server doesn't consider focused.
    Enter never triggers this since there's no click for anything to
    mis-a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
    [launcher.py, x11focus.py]
2026-09-23 Hide the launcher's cursor while an emulator runs; add temp focus diagnostics
    Basilisk II and Mini vMac both take over the cursor themselves once
    running, so the launcher's oversized custom pointer naturally disappears
    - LisaEm never touches cursor state at all, so it kept showing our
    cursor on top of LisaEm's own screen for the whole session. Explicitly
    hide it in _launch_selected and restore it once the emulator exits,
    rather than depending on each emulator's own behavior.
    Also adds a temporary diagnostic to lisa-run-with-led.sh: polls
    xdotool getactivewindow every second while LisaEm runs, logged to
    ~/lisa-focus-diag.log, to track down why mouse-click-launched LisaEm
    still doesn't receiv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
    [launcher.py]
2026-09-23 Disable SDL's mouse auto-capture to fix LisaEm mouse freeze on click-launch
    A focus diagnostic (xdotool getactivewindow polled every second while
    LisaEm ran) showed LisaEm correctly had real X input focus the entire
    time, ruling out the window-manager-focus theory the previous two fixes
    (release_pointer_grab, release_focus_to_pointer_root) targeted - focus
    was never actually the problem.
    New theory: SDL2 auto-captures the mouse on a button press by default,
    releasing only once SDL itself processes the matching button-release.
    Launching via mouse click goes straight from MOUSEBUTTONDOWN into a
    blocking subprocess.run() for the whole emulator session, so SDL never
    gets to pump that release -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
    [launcher.py]
2026-09-23 Restrict the "Emulator Launcher" desktop icon to Pi 3B; strip temp diagnostics
    The desktop-to-kiosk transition's vc4 kernel bug is confirmed Pi 4
    specific (a direct dmesg reproduction found nothing on Pi 3B) and
    unfixed after two mitigation attempts (a delay in back-to-kiosk.sh,
    max_framebuffers=1) - neither helped. Rather than keep chasing a kernel
    bug we can't fix from here, SETUP.md now says plainly: don't install the
    desktop icon on a Pi 4, use a reboot to get back into the kiosk instead.
    Q (kiosk -> desktop) itself is unaffected and stays available on any Pi.
    Also notes Pi 3B's poor LisaEm performance as a reason the icon may not
    be worth bothering with there either.
    lisa-run-with-led.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
2026-09-23 Wire Previous (NeXT emulator) into the picker
    Installed from the pre-built arm64 .deb (previous.nextcommunity.net) -
    no source build needed, and it bundles NeXT ROM images so no separate
    ROM sourcing either. Previous has no command-line flags at all; all
    config (machine type, ROM, disk, fullscreen) lives in
    ~/.config/previous/previous.cfg via its own in-app F12 settings GUI, set
    up once interactively at the Pi.
    - config.json: next entry now runs /usr/bin/previous instead of the
    /bin/sleep placeholder.
    - launcher-watchdog.sh: recognizes a running `previous` process so the
    watchdog doesn't restart the kiosk out from under it.
    - docs/software-setup.md: new section documenting the install a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
2026-09-23 Wire LinApple + Total Replay into the picker for Apple II emulation
    Installed from the pre-built arm64 .deb (github.com/linappleii/linapple)
    - bundles its own Apple II ROMs, no separate ROM sourcing needed. Boots
    straight into Total Replay (archive.org's ready-to-play hundreds-of-games
    ProDOS hard disk image) via --hd1/--autoboot/--fullscreen.
    Two real packaging bugs in this beta's arm64 .deb, both confirmed and
    fixed on hardware: libSDL3_image.so.0 isn't declared as a dependency at
    all (needs a separate apt install), and the binary links against
    libzip.so.4, which doesn't exist on trixie (renamed to libzip.so.5) -
    apt's libzip4|libzip-dev fallback satisfies the packaging check but not
    the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
2026-09-25 Extend the GPIO power button to Basilisk II and Previous
    Each dispatch verified via upstream source review, not guessed:
    - Basilisk II: a window-close request (xdotool windowclose) triggers its
    SDL_QUIT handler, which fires a genuine ADB Power keypress
    (ADBKeyDown(0x7f)/ADBKeyUp(0x7f) in src/SDL/video_sdl.cpp) - classic
    Mac OS treats this exactly like a real Mac's power key.
    - Previous: F10, its already-documented clean-shutdown key.
    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
2026-09-25 Drop the Basilisk II power-button handler - confirmed non-functional on real hardware
    Tried two mechanisms directly on Pi4: xdotool windowclose targeted at
    the correct window (verified by PID via the full X window tree, not
    guessed), and a raw WM_DELETE_WINDOW ClientMessage sent to that same
    window via python3-xlib. Neither had any effect - the guest stayed at
    the normal desktop, no shutdown dialog, process never exited. The
    upstream cebix/macemu source maps SDL_QUIT to a real ADB Power keypress,
    but Debian's basilisk2 package (man page dated 2002, later relinked
    against SDL2) apparently doesn't share that event-handling code path.
    Basilisk II now falls into the same "ignored, shut down fro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
2026-09-25 Light the power LED while Previous is running
    Mirrors lisa-run-with-led.sh's pattern for LisaEm: previous-run-with-led.sh
    lights GPIO18 for as long as Previous runs, off on exit however it
    exits. Signals to the user that the power button will do something (it
    sends Previous F10, per lisa-power-button-watcher.sh). config.json's
    next entry now runs the wrapper instead of /usr/bin/previous directly.
2026-09-25 Wire the power button and LED to LinApple
    User-confirmed on real hardware: F12 cleanly quits LinApple. The button
    now sends it while LinApple is running (lisa-power-button-watcher.sh),
    and linapple-run-with-led.sh lights GPIO18 for as long as it runs,
    mirroring the LisaEm/Previous wrappers - the LED now signals "the power
    button will do something" for all three emulators that support it.
    config.json's apple2 entry runs the wrapper (forwarding all args to the
    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
2026-09-25 Bring documentation up to date: Pi3/Pi4 divergence, stale placeholders, CLAUDE.md rewrite
    - CLAUDE.md: full rewrite reflecting current reality - five emulators
    (was three, with NEXT/APPLE II still /bin/sleep placeholders), the
    Pi3/Pi4 hardware divergence decision (Pi3 stays on LisaEm/Basilisk
    II/Mini vMac only, no power headroom for Previous/LinApple), the
    LED-wrapper pattern and which emulators do/don't support the GPIO
    power button and why, and a refreshed Known Open Items section
    (Q/desktop-icon Pi4 limitation, the LisaEm mouse-capture fix).
    - SETUP.md: fixed the stale "NEXT and APPLE II are unimplemented
    placeholders" gap (they're not, as of this session) and added a clear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
2026-09-25 Redesign the picker as a "CHOOSE YOUR ADVENTURE" card grid
    Replaces the single-row icon+label picker with bordered item cards
    (icon, name, subtitle) in a title/rule/grid/rule/footer panel layout,
    matching a supplied mockup. Also disables (but doesn't delete) the
    Lisa-style CPU/MEM/I/O/EXPANSION boot-diagnostic animation - the picker
    now shows immediately on launch.
    - theme.py: new card-grid layout constants (ITEM_BOX_*, RULE_*, a
    SUBTITLE_FONT_SCALE for the smaller subtitle line), panel re-centered
    vertically for the taller layout, TOP_STRIP_HEIGHT removed.
    - bitmap_font.py: added "<"/">" glyphs for the footer's "< > SELECT"
    hint.
    - rendering.py: draw_top_strip removed; new draw_item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
    [bitmap_font.py, launcher.py, rendering.py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]
2026-09-26 Add case STL files, document print quantities, and start a bill of materials
    hardware/3d-models/: adds the actual STL files (front panel, two back
    variants with/without a power-button cutout, power button cap, LCD
    clips, badges) plus a multi-plate .3mf slicer project. README documents
    each part, flags the two qty2 clip parts (print two, not one), and
    clarifies the two back pieces are alternatives (pick one based on
    whether you're wiring the physical power button), not both.
    hardware/bill-of-materials.md: new - everything besides the printed
    parts (Pi, LCD panel + controller, power supply, buck converter, barrel
    jack, toggle switch, keyboard switch, LED, wiring). Flags one real data
    issue fo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
    [Lisa-Mini-Pi_All-Plates.3mf, Lisa-Mini-Pi_Back-NO_Power_Button.stl, Lisa-Mini-Pi_Back-With_Power_Button.stl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]
2026-09-26 Document work-in-progress status and near-term hardware directions
    README.md and CLAUDE.md both now note three hardware explorations in
    progress (none started): an iPad 3/4 panel for higher resolution, fitting
    a Pi 5 + power regulation board in the case, and an 11.6" widescreen
    panel. The last one is flagged as needing real software changes (the
    picker's layout is hardcoded for a fixed 1024x768 4:3 panel throughout
    theme.py), not just a case redesign - so a future session doesn't treat
    it as a small tweak.
2026-09-26 Add recommended microSD card size to the bill of materials
    32GB, based on real measured usage on a fully-loaded Pi 4 (13GB used of
    a 29GB card, 2026-09-26) - 64GB if more margin is wanted.
2026-09-27 Make S SHUT DOWN and Q QUIT footer text clickable, add shutdown confirmation
    Lets a mouse-only kiosk setup shut down the Pi without a keyboard. The
    footer's combined "S SHUT DOWN Q QUIT" string is split into two
    separately hit-testable regions (rendering.py's footer_layout()/
    hit_test_footer(), mirroring the existing item_layout()/hit_test()
    drawing-vs-hit-testing symmetry pattern), wired into launcher.py's mouse
    handler alongside the existing S/Q keys.
    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
2026-09-27 Add clickable SHUT DOWN/QUIT confirmation dialog, higher-res launcher icons
    SHUT DOWN and QUIT are now individually clickable footer buttons (hover-
    highlighted, padded click targets) instead of keyboard-only hints, and
    both trigger a confirmation dialog (mouse or keyboard) before actually
    powering off or switching to the desktop - too disruptive to fire on a
    single accidental key/click. Reboot (R) is intentionally left untouched.
    Replaces the picker's generic placeholder icons with higher-res
    monochrome pixel-art versions (Lisa, Mac OS 6/7, NeXT, Apple II),
    resized to the launcher's fixed 128x128 icon size.
    [launcher.py, rendering.py, state.py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]
2026-09-27 Fix and fill in SETUP.md gaps found during a real Pi 5 setup pass, add README Controls section
    SETUP.md had several real gaps a fresh setup actually hits, all confirmed
    live on a Pi 5 during this pass:
    - §1 (flash the OS) was too terse to follow blind - no mention of a
    second computer/card reader, the Imager's current menu layout, or SSH
    basics (opening a terminal, the host-key prompt, invisible password
    entry).
    - §3's LisaEm clone was missing --branch lisa-fixes-1024x768 and used
    the wrong directory, silently building a binary lisa-run-with-led.sh
    could never find - a pre-existing bug the file's own Known Gaps
    section had flagged but never fixed.
    - §3's wxWidgets build was a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
2026-09-27 Add full GPIO wiring diagram, fix BOM resistor/switch-link gaps
    Adds hardware/pi-wiring-diagram.svg (buck converter power, switch, LED -
    exact pins and resistor values), referenced from software-setup.md §2,
    the BOM, and the assembly placeholder.
    Fills in two gaps the BOM had flagged as open (both confirmed on real
    hardware, 2026-09-27): the keyboard-switch link was a duplicate of the
    unrelated Dupont-wires link (replaced with a working listing, currently
    out of stock); no LED resistor value was specified (330Ω, same as the
    power-button switch's resistor - both confirmed by the wiring diagram).
    Also documents that the buck converter powers the Pi through the GPIO
    header's 5V/GND pins (2/6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
2026-09-27 Write real assembly instructions from a confirmed build, note future iPad 3/4 + Pi 5 revision
    hardware/assembly/README.md was an empty placeholder; replaced with the
    full step-by-step build (Pi mounting, power jack/rocker switch wiring,
    buck converter, power-button switch/LED wiring and mounting, LCD panel
    and controller board mounting, final assembly and power-on test),
    transcribed from a real, confirmed build on 2026-09-27 rather than
    guessed. Includes the screw-mount fragility warning (all four cracked on
    one build) and the hot-glue fallback that was actually used.
    Fills in BOM gaps the new instructions surfaced: heat-shrink tubing,
    M3x4mm screws, the small Pi-mounting screws, optional K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
2026-09-27 Clarify actual Pi hardware support status, fix BOM barrel jack link
    The README/BOM/3d-models docs previously implied Pi 4B and Pi 5 were
    equally recommended, sized purely on performance. Corrects that: the
    full software stack is confirmed working end-to-end on Pi 3, Pi 4, and
    Pi 5, but Pi 4 is the only one this case's current power wiring actually
    supports reliably - a Pi 5 needs its own dedicated power board for
    reliable GPIO power delivery, and the case has no mounting for one yet
    (a separate, more fundamental gap than the iPad 3/4 + Pi 5 combo noted
    as a future exploration, which is a nice-to-have on top of it, not a
    substitute). Pi 3 works but with materially worse emulator performance.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
2026-09-27 Add printing notes (settings, material) to 3d-models README
    Carries over general-purpose settings and the Polar Filament Retro
    Platinum PLA recommendation from the same builder's LisaFPGA case
    (github.com/wottle/lisa-mini) - a different, larger case design, but the
    material choice and general wall/infill/layer-height settings transfer.
    Explicitly does not carry over that doc's per-part orientation/support/
    bed-size specifics, since those are tied to that case's own STL geometry
    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
2026-09-27 Add real build photos to the assembly guide
    19 photos from an actual build (2026-09-27), placed against the matching
    step in each of the 9 build sections - resized/compressed from the
    originals (each ~10MB) to ~1600px-wide JPEGs. Covers everything except a
    full teardown, which the builder didn't want to do just for photos.
2026-09-27 Add missing buck converter voltage calibration step
    A real, safety-relevant step was missing from §5: the buck converter's
    output must be calibrated to ~5.1V with a multimeter (power connected,
    rocker switch on) before ever wiring it to the Pi's GPIO pins - these
    converters ship set to an arbitrary voltage, not necessarily safe for
    the Pi. Also adds a multimeter to the BOM's tool list and flags the
    buck converter as adjustable/needing this calibration every time.
2026-09-27 Add LCD metal-tab fitment step, link wiring diagram from SETUP.md
    Some iPad LCD panels have small metal screw-down tabs on three edges
    that don't sit flush enough for the panel to fit the case as printed -
    confirmed on a real build, fixed by bending the tabs flat or trimming
    them with wire snips. Added as its own step, before the panel ever goes
    into the case, since finding this out after a clip is already screwed
    down is the wrong order.
    Also links hardware/pi-wiring-diagram.svg from SETUP.md's Hardware
    section - it was already linked from docs/software-setup.md §2, the
    BOM, and the assembly guide, but SETUP.md itself only cross-referenced
    those files for GPIO wiring rather than pointing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
2026-09-28 Lay out README screenshots as a captioned 3-column grid
    Plain full-width image links made each screenshot huge and uncaptioned.
    Switches to an HTML table (GitHub renders this fine in Markdown) with
    each image at 1/3 width and a caption underneath.
2026-09-28 Make software-before-hardware ordering explicit
    Neither the main README nor the assembly guide said which order to do
    things in. Adds an explicit note in both: get the Pi fully working on
    the bare board first, then build the case around it - debugging is much
    easier before everything is sealed up.
